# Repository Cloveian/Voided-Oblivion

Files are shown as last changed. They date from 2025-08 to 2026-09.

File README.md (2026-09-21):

# Voided Oblivion

**An infinitely\* tileable analog hall-effect keyboard.** 5×6 ortholinear tiles that snap together edge to edge in any\*\* arrangement, two tiles for a 60%, three for an 80%, four for
full size. Each tile is a complete unit with its own RP2350B, dual USB-C PD ports, and power
system.

Designed by **Clover**

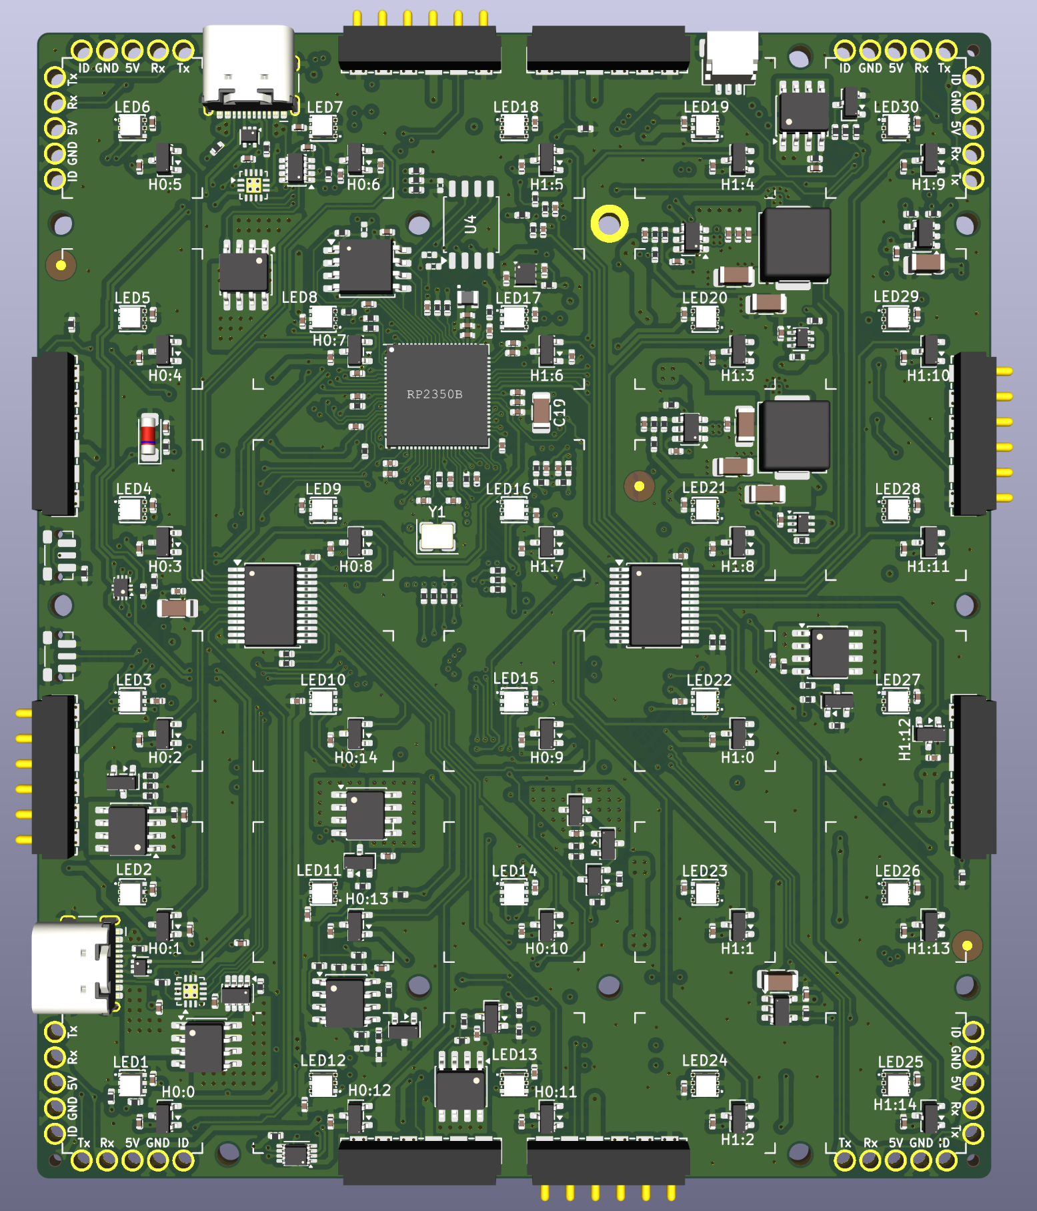
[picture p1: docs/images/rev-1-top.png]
Voided Oblivion, top

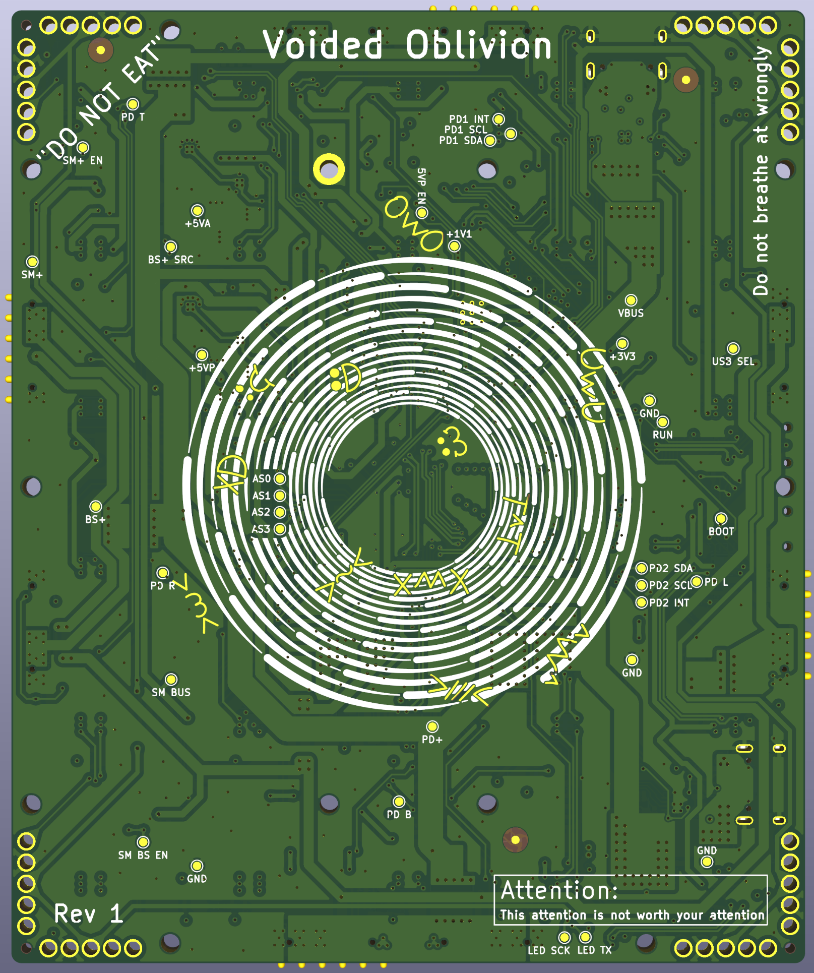
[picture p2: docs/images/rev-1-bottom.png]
Voided Oblivion, bottom


**Status: design complete, ordering boards.**

<sub>* not actually infinite but like way more than reasonable.</sub>
<sub>** in a grid, and not 6x5 to 5x6, individual tiles need to be the same orientation (portrait or landscape; they can be rotated 180° tho)</sub>

---

## At a glance

| | |
| --- | --- |
| **Board** | 4-layer, ~425 components, 242 nets |
| **MCU** | **RP2350** (used like 44/48 GPIO, i dont think i used enough 𐔌˙.) |
| **Dual USB** | 2 USB-C ports for ease of use when rotating the module(s) 90° |
| **Power** | FUSB302 PD port(s), TPS54302 bucks, comparator-based VBUS→PD/BS handoff |
| **Sensing** | Analog hall effect, 74HC4067 muxes into the ADC, 30 keys/tile |
| **Performance** | 1000 Hz polling, sub-1 ms latency, rapid trigger (in theory, if firmware is good at firmware-ing) |
| **Time** | ~100 hours spent on this project |

---

## The parts i find most interesting/difficult

**Stupid people ~~proofing~~ resistant-ing.** *so* many things would have been so much easier if i were just designing this for myself, but i'm not. i had to think of random scenarios like *'what if someone plugs both USBs in at the same time?'*, i had to add protection circuits for that. 'what if someone wanted to put 64 of them together?' (ok that one i would do if i had that many >w<) and minimizing the damage that a short between the outer pogo pins can do, and several other random things that i would just think 'i wont do that'

**Power system.** this project uses USB power delivery for 2 main reasons. non PD is not enough power for more than like 1 tile (with rgb) and with PD i can run a higher voltage across the whole network without worrying about voltage drop. But PD comes with its problems, the switch from 5v to higher voltages, i designed a comparator based system so all the power routing would happen with hardware so a firmware mistake ~~wouldn't~~ couldn't fry anything.
→ [power](docs/schematic-design/power.md)

**Everything budgeted onto one MCU.** 44 of 48 GPIO, 6 of 8 ADC channels, 12 of 12 PIO state machines. The interesting thing is that PIO uart is faster than hardware uart.
→ [pin budget](docs/design-choices/pin-budget.md)

---

## What's in here

| | |
| --- | --- |
| [`Voided-Oblivion/`](Voided-Oblivion/) | KiCad files |
| [`docs/`](docs/) | the design documentation |
| [`layouts/`](layouts/) | (proposed) keymaps made with [keyboard-layout-editor](http://www.keyboard-layout-editor.com/) |
| [`graphics/`](graphics/) | silkscreen art |

I removed the Datasheets from repo cuz they're manufacturer IP, and i would like to not make any enemies
[`docs/datasheets.md`](docs/datasheets.md) indexes every part and where to get its datasheet.
`old/` (the first attempt) is out of the working tree but still in git history.

## Reading the docs

These are working engineering documents, they were written during the design process (how it should be), and i keep incorrect reasoning/assumptions to remember *why* something changed

- **design**
	- [chip list](docs/chips.md)
	- [schematic ~~meth~~ math](docs/schematic-design/index.md)
- **features n' stuff**
	- [design decisions](docs/design-choices/index.md)
	- [goals and constraints](docs/goals.md)
- **sanity check(s)** (check if my sanity was still intack after reading so much (not quite) 'ai slop' ꩜ ᨓ𖦹)
	- [design reviews](docs/schematic-review-2026-08-08.md)
	- [datasheet research](docs/research/README.md)

## Licence

[CC BY-NC-SA 4.0](LICENSE.md), with a relaxed NonCommercial term so it only catches people actually making money. Mostly just do whatever, i would like some credit tho (,,¬﹏¬,,)

The carve-outs (full stuff in [LICENSE.md](LICENSE.md)):

- **Under US$1,000/year in revenue, sell freely.** No permission needed, nothing owed. The NonCommercial term is just to stop some small-medium sized company profiting off *my* work. I support the community and don't want to stop group buys or making a few for a friend or something like that.
- **If you do want to sell** (more than $1000) just talk to me (issue probably works) we can work out some sort of compensation. I probably won't say no.
- **The connector interface(s) are public domain** anyone can make/design their own submodule or even own tile if they want, it's encouraged ദ്ദി ˉ͈̀꒳ˉ͈́ )✧ 

## On LLM use

i used LLMs while working on this, ima just say how they were used.

**what they did:** the [datasheet research pages](docs/research/README.md) were written by agents that were given a datasheet and what the chip was supposed to do, and *not* shown my schematic so their conclusions could be diffed against what i'd actually designed. same shape for the [review passes](docs/electrical-review-2026-08-20.md), caught errors i made by looking at things too close. they also helped with editing the docs some, and wrote some of the tooling in `scripts/`.

**what they didn't:** ideas, design decisions, the modular architecture, the schematic, and the layout are mine. all the ideas in [schematic-design](docs/schematic-design/index.md) are mine. for example, some of the LLM research was different than what i had designed in the schematic, it exposed some mistakes i had made, and sometimes the research was backwards and would have me make a switch that couldn't turn on. the actual choices genuinely couldn't be made by a llm and this still be a good project

also a lot of the reviews were mostly useless/irrelevant 'fluff' (immediately dismissable with 0.8ms of thought with context (￢ \_￢ ) ) but did actually catch real stuff that needed fixing

also, and i say this as someone who has spent over 100 hours on this project: LLMs could *not*
have done this. they really, really suck at it. trust me, i would know.

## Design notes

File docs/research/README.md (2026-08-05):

# Datasheet research (auto-generated)

These pages are **not written in my voice** and are **not design decisions**. Each one was produced by an agent that was given:

- the project's power architecture and constraints,
- the role a given chip has to play,
- the datasheet,

and *deliberately not shown the current schematic*. So each is an independent "here's what the datasheet says the right way to do this is," written without knowing what I actually drew.

The point is to **diff them against the as-built design** and see where they disagree. Where they agree, that's a cross-check. Where they disagree, that's either a bug in my schematic or a thing the agent missed - and either way it's worth a look before fab.

Values here are *proposals*, not decisions. Anything I adopt gets written up properly in [schematic-design](../schematic-design/index.md) with my own reasoning, and the part lands in [chips](../chips.md).

**Caveat added after these were written:** the agents were briefed that i was hand-assembling on a hotplate with low-temp bismuth paste. **that's no longer true - this is going to JLC assembled.** so anywhere one of these pages rejects a package or a part on *solderability* grounds, that reasoning is void (the sourcing, cost and PCB-design-rule arguments still stand). The affected calls are the MAX40203 WLP package in [ldo-and-ideal-diode](ldo-and-ideal-diode.md) and the reflow-profile discussion in [sk9822-and-level-shifter](sk9822-and-level-shifter.md). Background in the [hall-effect re-revisit](../design-choices/hall-effect-sensors.md#re-revisit-im-not-assembling-this-myself-anymore).

**There is deliberately no RP2350B page here.** That one's the centrepiece of the whole design and the reasoning *is* the project, so i'm doing it myself rather than reading someone else's summary of it. Its working goes in [mcu](../schematic-design/mcu.md) like everything else i actually decide.

---
Back to [main index](../index.md)

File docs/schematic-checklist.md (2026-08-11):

# Single-Tile Schematic Checklist

Everything that has to land in the KiCad schematic for **one tile**. Pulled from [chips](chips.md), [pin-budget](design-choices/pin-budget.md), [power](design-choices/power.md), [comms](design-choices/comms.md), [hall-effect-sensors](design-choices/hall-effect-sensors.md), and [module-connectors](design-choices/module-connectors.md). One tile does everything - no second MCU - so this is the whole board.

Pin numbers are the **starting assignment** from [pin-budget](design-choices/pin-budget.md#a-starting-assignment) (KiCad gets final say when routing). Budget targets: **44/48 GPIO, 6/8 ADC, 12/12 PIO SMs.**

---

## 1. MCU + boot

- [ ] **RP2350B** (QFN-80), 1×
- [ ] Decoupling: 100nF per power pin + bulk caps per datasheet
- [ ] Crystal (12MHz) + load caps, or confirm using internal - Void needs accurate USB so **crystal**
- [ ] USB DP/DM to the USB mux (see §6), with 27Ω series + ESD if not handled by mux
- [ ] BOOTSEL button (or test pad) for UF2 flashing
- [ ] RUN/reset button or pad
- [ ] SWD header (SWCLK/SWDIO/GND/3V3) - do **not** skip, you'll want it
- [ ] **W25Q128JVS** 16MB QSPI flash on the QMI bus (steno dict)
  - [ ] Resolve first: boot flash only, or this as a 2nd chip on **CS1n (GPIO19)**? Checklist assumes 2nd chip (37/48). If boot-only, drop GPIO19 → 36/48.
- [ ] FIDO2 = TrustZone, internal, **no external secure element to wire**

## 2. Power - rails & regulators

See [power](design-choices/power.md) for the full flow. Three rails: **HV** (per-side switched), **bootstrap 5V** (always-on, shared), **clean 3.3V** (LDO). GND common everywhere.

- [x] **FUSB302BMPX** USB-PD PHY - I²C0 **SDA GPIO20 / SCL GPIO21**, **INT GPIO15**, CC1/CC2 from the active port (via CC mux, §6)
- [x] **TPS54302** ×2 (same part, 2 BOM instances):
  - [x] **Clean buck** (HV→5V, always-on) - input must work from ~5.5V (pre-PD) through 20V; feeds the LDO + OR's onto bootstrap
  - [x] **Big buck** (HV→5V, gated) - enable on **GPIO14**; feeds RGB + submodules
  - [x] Each: inductor, input/output caps, feedback divider for 5V per datasheet
- [x] **XC6220B331MR** 3.3V LDO off clean 5V - feeds MCU + hall sensors + mux (low-noise, this is the analog rail). **5-pin SOT-25 with a CE pin - tie CE to VIN** (always-on clean rail, must never gate off)
- [x] ~~**MAX40203**~~ → **LM66100DCKT** (C2832141) ideal diode - clean buck 5V → shared **bootstrap** net
  - [ ] **CE (3) → VOUT/BS+ via R15 0Ω** — always-on RCB. CE to GND silently disables reverse blocking
  - [ ] **C114 100nF → 1µF** on VIN, local to the part
  - [ ] **R83 100k: ST (5) → +3V3** (*not* VOUT — 5V would exceed RP2350's 3.6V pin max), ST → `BS+ SRC` GPIO
  - [ ] Pin 4 (N/C) → GND or no-connect flag
  - [ ] Symbol + footprint (SC-70-6) + Value + **LCSC** all move together — the BOM pulls Value

## 3. Power - VBUS handoff & HV switching (hardware, no firmware)

- [ ] **TLV1805** comparator watching VBUS vs ~6V resistor divider, drives two things at once:
  - [ ] **AO3415** P-FET: VBUS→bootstrap path, normally on, comparator turns OFF above ~6V
  - [ ] N-FET/switch: VBUS→local HV rail, normally off, comparator turns ON above ~6V
- [ ] **AO4407A** ×4 (Q4–Q7) - HV per-side switches (one per edge), SOP-8 P-FET, 30V/9.5mΩ, **≥2A continuous** design target against the connector's 4A ceiling. RC soft-start on gate (values below). ~~AO3401A ×4~~ - SOT-23 couldn't survive the connector's full current, [working](schematic-design/power.md#hv-per-side-switches---picking-the-fet)
  - [ ] **BC847B** (C20069135) ×4 - NPN level-shift, **Basic**. MCU GPIO0–3 → base → pulls the gate toward GND through R_soft
  - [x] ~~**BZX84C10** ×4 gate clamps~~ - **cut.** AO4407A is ±25V, and at the 9V default Vgs is only −8.6V (35% of rating). They'd protect the flagged 20V mode only, for ~32mm² of scarce board
  - [ ] Gate network per switch, [corrected values](schematic-design/power.md#gate-drive---the-researchs-values-are-backwards) - **the research's 39k/470k is backwards and won't turn on at 9V**:
    - [ ] **R_pu 100kΩ** gate→source · **R_soft 4.7kΩ** NPN collector→gate · **C_soft 100nF** gate→source
    - [ ] **Rb 10kΩ** GPIO→base · **Rbe 100kΩ** base→GND
    - [ ] → Vgs = −0.955 × PD+ (−8.6V @ 9V, −19.1V @ 20V), t_ramp ≈ 1ms, ~0.5A inrush
  - [ ] HV enable GPIO: **GPIO0–3** (one per side)
  - [x] ~~HV per-side current sense → ADC GPIO42–45~~ - **cut entirely, not even DNP footprints.** A DNP pad costs the same board area as a populated one, and area is the binding constraint. Re-decision + weighted table in [design-choices/power](design-choices/power.md#re-decision-does-this-need-per-edge-ocp-at-all)
    - **ADC budget drops 6/8 → 2/8. GPIO42–45 are free.**
    - **!firmware-note!** **FIRMWARE now owns overcurrent** - limit topology *before* enabling a path, using the tile map it already builds. Prevention, not tripping
- [ ] **Wire the switch source to PD+ and the drain to the connector**, not the reverse - that orientation points every tile's body diode inward, so two neighbours with both switches open sit diode-to-diode and the edge net floats. Flipped, every tile permanently powers its neighbours. [why](schematic-design/power.md#the-body-diode---an-open-switch-only-blocks-outbound)
- [ ] **!firmware-note!** **FIRMWARE: turn an edge switch OFF on neighbour loss.** An edge left enabled after a tile is yanked makes the next hotplug a hard hot-insert - the new tile's bulk charges through its own body diode with no soft-start in the path. This is what makes the Rx pull-down detection in §7 load-bearing
- [ ] **SS54** Schottky ×(per VBUS→HV path) - backfeed protection (40V/5A)
- [ ] Hold-up caps on bootstrap to cover the µs comparator→buck handoff

## 4. Key sensing

- [ ] **GH39F** hall sensor ×30 (5×6) - generic 3-pin SOT-23 footprint (Vcc/OUT/GND) so any analog hall drops in
- [ ] **74HC4067** 16:1 analog mux ×2
  - [ ] Mux outputs → ADC **GPIO40, 41**
  - [ ] Shared 4 select lines → **GPIO8–11**
  - [ ] 30 keys into 32 channels = 2 spare channels (leave unconnected/test pads)
- [x] ~~Consider sensor **bank-power gating**~~ - **decided against** ([working](schematic-design/keys.md#sensor-bank-power-gating)). Fixed the LDO instead. Do route sensor VDD as its own net with a 0Ω link to +3V3 so it can be retrofitted.
- [ ] Tie the 2 spare mux channels (AM0:15, AM1:15) to GND - currently floating
- [ ] Sensors on the **clean 3.3V** rail, kept off the noisy buck

## 5. RGB

- [ ] **SK9822-EC20** ×30 - daisy-chained
- [ ] Hardware **SPI0**: SCK **GPIO34**, TX(MOSI) **GPIO35**
- [ ] Powered from the **big (gated) buck** 5V, NOT the clean rail
- [ ] **SN74LVC2T45** level shifter 3.3V→5V on SCK/data - **required**, not conditional (SK9822-EC20 VIH min 3.4V > the 3.366V the 3V3 rail can manage). VCCA→3V3, VCCB→gated-5V, DIR high. 22–33Ω series on the 5V side. See [rgb calcs](schematic-design/rgb.md#picking-the-level-shifter)
- [ ] Bulk cap near the LED chain; per-LED decoupling per density

## 6. USB-C (dual port + mux)

- [ ] 2× USB-C receptacles (one horizontal edge, one vertical edge - for 90° reach)
- [ ] **TMUX1574PWR** - muxes CC1/CC2/DP/DM between both ports, single SEL driven by VBUS-A detect
  - [ ] 100Ω series on CC lines (ESD)
  - [ ] Rd pull-downs on the RP2350B side
  - [ ] VBUS-A → SEL detect circuit (resistor/transistor)
- [ ] Selected port's CC → single FUSB302 (§2); non-selected port can't negotiate (stays 5V)
- [ ] VBUS from both ports → backfeed protection (§3)

## 7. Inter-tile edge connectors (×4 sides)

Per side carries: **HV, Bootstrap, GND, Tx, Rx**. **Part picked: PG-6P-2.5-5.5H-SM-RA** (Shenzhen Yiwei), **2 per side** - one 6P male + one 6P female. Pinout is the palindrome with power ×4, gender split falling out of the two bodies - see [module-connectors](design-choices/module-connectors.md#revisit-i-picked-a-real-connector-and-it-killed-the-custom-cutout-idea):

```
GND  GND  HV   HV   BS   Tx   |   Rx   BS   HV   HV   GND  GND
<--------- 6P male --------->  |  <-------- 6P female ------->
pin:  1    2    3    4   5   6 |   1    2    3    4    5    6
```

**GND outboard** (deliberate - the most exposed contacts should be ground, not the 20V rail). Per body: male = `GND GND HV HV BS Tx`, female = `Rx BS HV HV GND GND`.

- [ ] Two footprints: **short (5un edge)** and **long (6un edge)** - like only mates like
- [x] **Gender rule: clockwise around the perimeter, every edge is male-then-female.** Top L→R, Right T→B, Bottom R→L, Left B→T. Two neighbouring tiles traverse the shared edge in *opposite* rotational senses, so male always lands on female. Drawn as J1/J3/J7/J5 male, J2/J4/J8/J6 female
- [ ] **Both bodies symmetric about the edge midline** - this is the one that silently maps HV onto Tx if you get it wrong
- [ ] HV/GND get **4 contacts each** (1A per contact → **4A per-side ceiling**, which is what sizes Q4–Q7 in §3)
- [ ] Rx line **pulldown, 4.7kΩ** per side to GND - **required by RP2350-E9**, which sources ~120µA and parks a floating input at 2.2V (phantom neighbour). 8.2k is the datasheet's boundary with only 171mV to VIL; 10k **fails**. [working](schematic-design/mcu.md#rp2350-e9-and-the-neighbour-detect-pull-downs)
- [ ] Tx series-termination footprint per side, **populate 0Ω** (pads for 22–33Ω if it rings at 4 Mbaud)
- [ ] **Inter-tile UART pins - all four sides on PIO** ([why](design-choices/comms.md#revisit-the-piosm-allocation-was-built-on-a-wrong-assumption)): the hardware UARTs moved to submodule corners, because the PL011 caps at **7.8 Mbaud** while a PIO UART does ~18.75 - the slow path was on the high-traffic links
  - [ ] **Top** GPIO12/13 · **Left** GPIO16/17 · **Bottom** GPIO4/5 · **Right** GPIO6/7 — all PIO (F6/F7/F8), uniform, **no F11 anywhere**
  - [ ] Pins no longer need to be UART-capable; left as-is to avoid churn
- [ ] ~~Footprint placeholder pending pogo-vs-spring-finger prototype~~ - **resolved**, it's an off-the-shelf pogo pair. Footprint still needs drawing from the part drawing
- [ ] **No inset sequencing is possible** with molded bodies - all 12 contacts break together, so hot-unplug safety rests on PD voltage. Default **9V** - unconditionally under gold's ~15V minimum arcing voltage. (**not 12V** - 12V isn't a required PD step, the Power Rules give 9/15/20. 15V is only arc-safe breaking ≤1 tile, since an arc needs 15V **and** 0.4A.) 20V behind an explicit firmware flag + warning

## 8. Submodule corner connectors (×4 corners)

**5-pin** (revised from 4 — [working](design-choices/submodules.md#revision-5-pins-not-4---adding-a-senseid-line)), clockwise-consistent at every corner:

```
ID   GND  5V   Rx   Tx
 1    2    3    4    5
```

- [ ] **`ID GND 5V Rx Tx`** — prepend ID, don't append. 5V must stay **interior** (a misaligned module can't land it on a signal pin); ID sits at an end next to GND, the quietest pin
- [ ] 5V from the **submodule group switch** (below); independent UART per corner, not muxed
- [ ] Corner Tx/Rx → **GPIO22–29** — **2 corners on hardware UART, 2 on PIO**:
  - [ ] **GPIO24/25 = UART1 TX/RX (F2)** and **GPIO28/29 = UART0 TX/RX (F2)** — the only two pairs in that range that are TX/RX at F2, and conveniently on *different* UARTs
  - [ ] **GPIO22/23 and GPIO26/27 on PIO** — both are UART1 CTS/RTS at F2, so they could never have paired with each other anyway
- [ ] **ID → 4× ADC-capable GPIO** (from GPIO42–47), **pull-up to +3V3** (not 5V), **series ~10kΩ** to the pin — the module is an untrusted 5V load
- [ ] **Corner power is dual-sourced** so submodules work on a 5V-only (non-PD) source - [working](design-choices/submodules.md#corner-power-dual-sourced-so-submodules-work-without-pd)
  - [ ] **U15 LM66100DCKT**: +5VP → SM_BUS, **CE→VOUT via 0Ω** (always-on reverse blocking). No GPIO — +5VP is genuinely 0V pre-PD, so there's nothing to arbitrate
  - [ ] **U12 AP2171WG-7**: BS+ → SM_BUS, EN = `SM BS EN`. **!firmware-note! Firmware rule: enable only while `BS+ SRC` reads low** (clean buck not feeding BS+)
  - [ ] **U16 AP2171WG-7**: SM_BUS → SM+, EN = `SM EN`. This is the independent gate — U15 has no enable, so without it the only post-PD off-switch is the big buck, which kills RGB too
  - [ ] **Both AP2171W enables: 4.7kΩ pull-down to GND** — *not* 100k, *not* 0Ω. RP2350-E9 parks a floating pad at 2.2V, above the EN threshold, so a mis-configured pin can turn the rail **on**
  - [ ] **U16 /FLG → `SM FLT` GPIO** with 100k pull-up to +3V3. **U12 /FLG and U15 ST: no-connect flags, no pull-ups** — U12 is in series with U16 at the same 1A so it reports the identical fault, and U15's ST duplicates `BS+ SRC`
  - [ ] Caps: 1µF at each IN, 10µF on SM_BUS and SM+
  - [ ] **CHECK BEFORE FAB: does AP2171W's OCP latch or auto-retry?** If it latches, U16's EN is the only fault reset
- [ ] Mechanical keying (shrouded header / asymmetric mount) — pin order limits misinsertion damage, it doesn't prevent it
- [ ] **4-pin machined (Swiss) socket → now 5-pin**, socket on the tile

**Notes:** the ID divider runs off +3V3, so presence and identity work **with the corner rail switched off** — firmware can read what's plugged in before deciding to power it. A module needs **no MCU**: firmware just doesn't configure UART on Tx/Rx and uses them as GPIO.

**Not provided:** 5V-only (non-PD) operation, and submodules-alive-with-RGB-off. The switch is downstream of +5VP so it can only remove power. RGB dimming is the SK9822 global-brightness lever, not a rail gate.

## 9. Pin assignment cross-check (paste into schematic notes)

| Pins | Use |
| --- | --- |
| GPIO0–3 | HV per-side enable |
| GPIO4/5 + 6/7 | Inter-tile Bottom + Right (UART1) |
| GPIO8–11 | Key mux select lines |
| GPIO12/13 + 16/17 | Inter-tile Top + Left (UART0) |
| GPIO14 | Big buck enable |
| GPIO15 | FUSB302 INT |
| GPIO19 | Steno flash CS1n (if 2nd chip) |
| GPIO20/21 | FUSB302 I²C0 SDA/SCL |
| GPIO22–29 | Submodule corners (4× Tx/Rx) |
| GPIO34/35 | RGB SPI0 SCK/TX |
| GPIO40, 41 | Key mux A/B ADC outputs |
| GPIO42–45 | **Submodule corner ID / analog** (4× ADC) |
| **Spare** | GPIO18, 30–33, 36–39, 46, 47 (11 free) |

**ADC:** 6/8 used · **GPIO:** 44/48 used · **PIO SMs:** 12/12 (RGB on HW SPI; **4 inter-tile sides on PIO = 8**; 2 submodule corners on HW UART, 2 on PIO = 4)

## 10. Before first PCB / sanity

- [ ] ERC clean
- [ ] Confirm every ADC-needed net actually lands on GPIO40–47 (hard constraint)
- [ ] Confirm both RGB SPI nets are the **same** SPI instance
- [ ] Test points: 3V3, 5V bootstrap, HV, GND, key-mux out, a couple UART lines
- [ ] Decoupling sweep - every IC has its caps
- [ ] **Blocked-on-hardware** (don't gate the schematic, just remember): case-magnet field vs hall saturation, pogo vs spring-finger, XC6206/MAX40203 downgrade triggers

---

Back to [index](index.md).

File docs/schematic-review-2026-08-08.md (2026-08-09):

# Voided Oblivion — Schematic Design Review

**Date:** 2026-08-08 · **Scope:** `Voided-Oblivion/Voided-Oblivion.kicad_sch` (+ `keys.kicad_sch`, `power.kicad_sch`), KiCad 10 · **Analysis run:** `analysis/2026-08-08_2107/`

## Verdict

**The schematic is in very good shape.** No board-killing electrical error was found. Every IC subsystem was traced pin-by-pin and, where datasheets exist, verified against the manufacturer PDF. The design closely follows the RP2350 hardware design guide where it applies, and the project's own docs (`docs/schematic-design/*`) already contain unusually rigorous derivations that the schematic matches. What remains before fab: **the sourcing gap (1% MPN coverage), a PCB that is one design generation behind the schematic, and a short list of latent/provision bugs and cheap-insurance items below.**

## Analyses run

| Analysis | Status | Result |
|---|---|---|
| `analyze_schematic.py` | ✅ | 374 components, 280 nets, 120 findings (4 error, 17 warning — triaged below) |
| `analyze_pcb.py --full` | ✅ | Used for sync check only — layout is mid-progress |
| `cross_analysis.py` | ✅ | 10 findings (all schematic↔PCB sync) |
| EMC (`analyze_emc.py`) | ✅ | 35.5/100 — **provisional**: findings are dominated by the unfinished layout (no ground zones/fills yet). Re-run after layout. |
| SPICE (ngspice) | ✅ | **35/36 subcircuits pass**, 1 warn (C37 — deliberately DNP, see below) |
| Thermal | ✅ | 0 findings (limited value until PCB is current) |
| KiCad ERC (`kicad-cli sch erc`) | ✅ | **1 error** — the intentional SM+ power-OR node (see F3) |
| Deep review + gate | ✅ | 14 findings verified, 0 quarantined (`analysis/deep_review.json`) |
| Gerber analysis | — | Not applicable — no fabrication outputs exist yet |
| Lifecycle audit | — | Not run — MPN coverage is 1%, nothing to query. Re-run after BOM backfill. |
| Prior review delta | — | First review; no prior review file found |

**Verification basis:** Datasheets in `Refrences/datasheets/` were used as ground truth (RP2350 datasheet + hardware design guide, TPS54302, LM66100, TLV431, LM2903, AO3401A, AO4407A, FUSB302, ABM8-272, W25Q128JV, 74HC4067, GH39F/SS49E, SK9822, SN74LVC2T45, TPD2E2U06, SS54, BZX84, BZV55, APH0630). The **TLV767 datasheet was missing and was fetched during this review** (TI SLVSE84D — recommend saving it to `Refrences/datasheets/`). The **AP2171W datasheet is missing** — U12/U16 are verified only against the KiCad library symbol and convention (see F3).

---

## Findings

### Warnings (fix or decide before layout freeze)

**F1 — CC1/CC2 are crossed on both USB-C ports.**
`USB1.A5 (CC1) → R49 → PD1.CC2` and `USB1.B5 (CC2) → R48 → PD1.CC1`; USB2/PD2 are crossed identically via R50/R51. For a UFP sink using only USB 2.0 data this survives — the FUSB302 measures both CC pins and just reports mirrored cable orientation — but anything orientation-dependent (VCONN targeting, future SS mux control) acts on the wrong pin. Either straighten it or add a schematic note making the cross deliberate so firmware knows to flip orientation.

**F2 — The second-flash CS provision can never work as drawn.**
The provision net named `GPIO0` contains only R9.1 and R11.1 — it is an island, not connected to U1 pin 77 (whose net is `PD EN TOP`). Populating U4/R11/R13 would leave U4's CS undriven (R13's pull-up would at least hold it deselected). Deeper problem: XIP_SS_N_1 exists **only on GPIO0, GPIO8, GPIO19, GPIO47** (verified in the RP2350 datasheet GPIO CTRL register map), and GPIO0/GPIO8 are spent (PD EN TOP, AS0). **Fix:** move the provision wire to GPIO19 or GPIO47 — both are currently unused stubs. Latent (everything involved is DNP), but it silently defeats the documented second-flash option.

**F3 — SM+ power-OR node: intentional, but carries the review's one ERC error and one unverified part.**
ERC flags `U12.OUT ∥ U15.VOUT` (power-output × power-output). The topology is right: U15 (LM66100, CE→VOUT via R16 = always-on reverse-blocking mode, same strap as U9/R15 and correct per LM66100 §8.3.2) ORs +5VP onto the node; U12 (AP2171W) switches BS+ onto it pre-PD; U16 gates the result to SM+. Two follow-ups: (a) add an ERC exclusion with a comment; (b) **the AP2171W datasheet isn't in the project** — confirm active-high EN, off-state reverse blocking, and current limit vs. SM+ worst-case load. Note that while U12 is enabled it conducts both directions, so if +5VP comes up with U12 still on, +5VP back-feeds BS+ — probably harmless at ~5V, but it's a firmware sequencing rule worth writing down.

**F4 — PCB is one generation behind the schematic.**
66 schematic components missing from the board; stale parts on it: U9 still MAX40203 (now LM66100), D3 still BZV55B**5V1** (now B**3V3**), C41 still 100µF on BS+ (now 1µF on +5VA), R48/R50 0Ω (now 100Ω), C76/C77/C114/R23 values stale. All match documented re-selects, confirming the schematic is truth. Run **Update PCB from Schematic** before any further layout; treat current EMC/PCB analyzer output as provisional.

**F5 — Sourcing blocker stands (SS-001).**
MPN fields readable by tooling: 1/77 unique parts (1.3%). The docs contain many settled picks (APH0630T100M C5349698, LM66100 C2832141, …) that aren't in symbol fields. Backfill LCSC/MPN/Manufacturer fields (the `bom` workflow can drive this) — it's the one thing that hard-blocks a JLC order.

### Recommendations (cheap insurance / open items from your own docs)

**F6 — ADC_AVDD is tied straight to +3V3.** The reference design does this too, but this board's entire key mechanism is 12-bit sampling of 30 hall sensors, and your docs call the supply chain feeding it "not characterised end-to-end" and "the first suspect." VREG_AVDD got an RC filter (R3 33Ω + C9 4.7µF); ADC_AVDD got nothing. Add a DNP-able filter provision (0Ω default, ferrite/33Ω + 1–4.7µF option) between +3V3 and pin 59. Costs nothing now, impossible after layout.

**F7 — Sensor-VDD split (keys.md's own to-do) is not implemented.** All 30 GH39F VDD pins tie directly to +3V3; the "0Ω link on its own net" that keeps the bank-gating retrofit possible does not exist yet.

**F8 — R30/R31 tolerance not encoded.** power.md's margin analysis wants 0.5% here (worst-case LTP 5.52V RSS vs the 5.5V vSafe5V ceiling — the thinnest margin on the board). U10 is already TLV431B (±0.5%) ✅; put the 0.5% tolerance in the R30/R31 fields so the BOM actually orders it.

**F9 — No ESD protection on submodule/inter-tile UART lines.** TPD2E2U06 covers both USB data pairs ✅. The 8 corner submodule UART lines (user-facing, hot-plug by design) and 8 tile-edge UARTs have none. Consider a 4-channel TVS per corner, or at least series resistors for hot-plug.

**F10 — No connector-side VBUS capacitance.** Connector VBUS nets carry only the FUSB302 sense pin and SS54 anodes; the only cap is C38 100nF behind the diodes. The deliberate 10µF-attach-limit strategy is sound, but ~1µF per port before D1/D2 would still be inside the limit and gives FUSB302 a cleaner measurement node.

**F11 — 100Ω CC series resistors (R48–R51).** Rd seen by the source becomes 5.2k (+2%, inside the 4.59–6.12k window) and BMC is unaffected — fine for a sink. VCONN *sourcing* through 100Ω is impossible, but a sink doesn't need it. Keep if intended as hot-plug/ESD damping; document why, since the PCB still has 0Ω.

**F12 — Five spare GPIOs (19, 38, 39, 46, 47) end in bare wire stubs.** Harmless, but label them or add test points; reserve GPIO19 or GPIO47 for F2.

**F13 — 22µF output caps (C28/C29/C34/C35) have no footprint/MPN yet.** When assigning, they must be ≥0805-class 6.3V+ X5R/X7R — a 0402 22µF loses ~half its capacitance at 5V bias, and the 44µF total is what the TI Table 7-2 stability design assumes.

**F14 — Doc drift:** power.md's LDO section still documents XC6220B331MR; as-built U7 is TLV76733. The swap is *good* (see below) — update the doc, and save the TLV767 PDF into `Refrences/datasheets/`.

### Analyzer false positives (triaged, no action)

- **PP-001 "U16.5 IN has no DC path to a power rail"** — the pin is fed by U15/U12 switch outputs on the OR node. Powered; false positive.
- **RS-001 "+5VA EN / +5VP EN have no declared source"** — they're enable nets that merely *look* like rails to the parser (`+5…` prefix). +5VA EN is U11B open-collector + R34 100k→3V3; +5VP EN is GPIO14 + R38 100k pull-down. Both correct. (Renaming, e.g. `5VA_EN`, would silence tooling.)
- **VM-001 "BS+ SRC 5V/3.3V domain crossing"** — BS+ SRC is the LM66100 open-drain status pin pulled to +3V3 by R83, exactly as your docs specify ("don't copy TI's pull-up rail"). Correct.
- **UC-003 "CC missing 5.1k pull-downs"** — Rd is integrated in the FUSB302. Correct as drawn.
- **UC-002 "no ESD on VBUS"** — partially true (see F10), but the D+/D- pairs *are* protected (U13/U14), and VBUS goes through Schottky ORing + soft-started FETs, not directly to loads.
- **SPICE warn on C37** — the TLV431 cathode cap the docs already recommend keeping DNP (unstable 6nF–400nF band). It *is* DNP. Consistent.
- **EMC errors (no ground plane, decoupling distance, IO filtering)** — artifacts of the half-built layout; re-run after F4.

---

## What was verified correct (the positive findings)

**RP2350B core (U1)** — all against the datasheet + hardware design guide:
- All 8 IOVDD pins → +3V3; 3× DVDD → +1V1; VREG loop verified: VREG_VIN=3V3, LX→L1 3.3µH→+1V1, FB sensed at +1V1, VREG_AVDD through R3 33Ω + C9 4.7µF (guide values), VREG_PGND→GND. USB_OTP_VDD→3V3 ✅
- Crystal: ABM8-272-T3 (the Pico 2 part, CL=10pF) + 15pF/15pF (CL_eff ≈ 10.5pF) + 1kΩ XOUT series — the guide's exact circuit ✅
- USB: DP/DM through 27Ω series (R7/R8) to the TS3USB30E mux ✅
- Flash: W25Q128JVS (the guide's own chip) on QSPI, CS strap network exactly per guide (R10 0Ω link, R1 DNF pull-up, R6 1k + BOOTSEL to GND); second-flash provision DNP (but see F2) ✅
- RUN: button-only, matching the Minimal/Pico 2 practice; SWD on dedicated J9 header ✅
- Pin budget matches `pin-budget.md`: 4 side UARTs, 4 corner submodule UARTs + 4 ADC ID lines, 4 PD-EN, I2C ×2 + INT ×2 for the PD PHYs, AS0–3 mux address, 2 ADC mux returns, LED SCK/TX, 5 power-control GPIOs, 5 spare ✅

**Power (all SPICE-checked, values match `power.md` derivations):**
- U5/U6 TPS54302: FB 100k/13.3k → 5.08V (Vref 0.596V per SLVSDG6C), 10µH APH0630T100M (Isat 4.57A vs 2.47A peak), 2×22µF out, bootstrap caps, feedforward 75pF ✅
- U7 TLV76733: **pinout verified against TI SLVSE84D Table 5-1** (OUT/SNS/GND/EN/GND/IN — the symbol is right), SNS→OUT, EN→IN via R12 0Ω (explicitly sanctioned; internal pull-up), CIN 1µF / COUT 4.7µF meet the 1µF minima — this answers power.md's open "is 1µF in OK" question with a datasheet **yes**. The WSON-6 pad also dissolves the XC6220 thermal ceiling that made bank gating load-bearing (≈+41°C at 400mA vs +113°C) ✅
- U9/U15 LM66100: CE→VOUT reverse-current-blocking strap on **both** (R15/R16) — the exact trap power.md warns about, avoided twice; ST pulled to +3V3 not VOUT ✅
- U10 TLV431**B** + R21 20k bias (188µA ≥ 2.35× IK(min)); R27 0Ω REF strap; C37 DNP per doc recommendation ✅
- U11 LM2903: VCC=VBUS (can't eat its own tail), A-side hysteresis on the reference node (R22/R46 → UTP 5.95V / LTP 5.68V), B-side clean 5.73V buck-enable — matches the doc's derivation; divider R30/R31 44.2k/12.2k confirmed ✅
- Q1 AO3401: off-divider R35 1M / R36 10k (Vgs −0.2V at 20V), **D5 gate zener present** — the single-fault clamp power.md recommended adding has been added ✅
- Q2/Q3/D4: gate network (R32/R29/R33/R47), D4 BZX84C10 clamp, C44 100nF Miller soft-start (~1–3ms PD+ ramp) ✅
- Per-side HV switches: 4× AO4407A (the doc's re-select away from SOT-23 thermal limits) + BC847 level shifters with 10k base/pull networks, drains to per-side PD nets on J1–J8 ✅
- SM+ chain: U12/U15/U16 with EN pull-downs (default off), FLG̅ pull-up 100k, BS+ SRC status to GPIO36 ✅

**USB/PD:** FUSB302 ×2 with VDD/VCONN on 3V3, I2C 4.7k pull-ups ×2 ports, INT pull-ups, VBUS sense direct to connector; TS3USB30E mux with OE̅ grounded, port-2-priority auto-select (USB2 VBUS → R37 10k → D3 3.3V clamp + C39 + R39 100k pull-down → S) — a clean hardware port arbiter; D1/D2 SS54 VBUS ORing ✅

**Keys & RGB:** 30× GH39F on +3V3 → AM0/AM1 (74HC4067, E̅ tied low via jumper, unused I15 grounded via R65/R66, 0Ω jumper convention on all select lines) → ADC0/ADC1; 30× SK9822 chain traced end-to-end (LED1→LED30, SDO/CKO chain intact, ends floating as expected), driven through SN74LVC2T45 (VCCA 3V3/VCCB +5VP, DIR strapped A→B, 33Ω series into the first LED; partial-power-down safe when +5VP is off) ✅

**ERC: 1 error total** (the intentional F3 node) — for a 374-component, 3-sheet hierarchical design that is remarkably clean.

## Review limits

- **AP2171W (U12/U16)** and **GH39FKSW** electrical limits verified only against library symbols/docs already in-repo; AP2171W PDF should be added (F3). GH39F's own PDF is present but thin (settling time unpublished — your keys.md already covers this).
- PCB, EMC, and thermal conclusions are deferred until the layout catches up with the schematic (F4).
- Lifecycle/pricing audit deferred until MPN backfill (F5).

*Full evidence-linked findings: `analysis/deep_review.json` (gate: 14 verified / 0 quarantined). Analyzer JSON: `analysis/2026-08-08_2107/`.*

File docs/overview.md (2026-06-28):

# Voided Oblivion

## What is this project?
This is a keyboard I have started, stopped, and restarted 3 times, but this time is different. This time I'ma actually write out my thoughts and design processes, so I can demonstrate my skills and abilities to future employers / college applications.
Also writing out my decisions will also make me more likely to not try and over achieve/cram as much stuff on this that can possibly fit.

The last 3 attempts didn't die because they didn't work, they stalled because i got too busy to finish, and by the time i came back i'd lost the thread and basically restarted, usually because i'd tunneled on a detail or wanted to cram in a new feature. So the real enemy here isn't technical, it's time. i'd get too busy, drop it, and by the time i came back i'd lost the thread. i've got the time this round, so writing everything down covers the rest: decisions stay made, and i can pick back up instead of starting over.

## What I'm working with
- Voron 2.4 (350mm$^{3}$) FDM printer
- Anycubic Photon mono x2 resin 3d printer
- Multiple soldering irons + hot air + 200mm$^{2}$ PCB reflow hotplate (SMD assembly)
- CNC that can in theory cut aluminum (never tested)
- Access to a very accurate laser powerful enough to cut aluminum

**Budget:** i'd like to stay around ~$250, but that's a guideline to keep me honest, not a hard limit.

## Background
This isn't my first keyboard. i've designed a Corne-shaped board in KiCad before, running a nice!nano v2 with Choc switches, per-key RGB, and resin-printed keycaps (back when i only had a worse-than-an-Ender-3 FDM printer and my resin one). So KiCad, per-key RGB, and printing my own caps are all known territory.

i'm also really good at 3D design in Fusion 360 (like, commission-level), and i daily-drive Arch.

---

The goals, constraints, and design decisions live in the [design doc](index.md).

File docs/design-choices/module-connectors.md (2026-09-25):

# Module Connectors

## Identify
I need to figure out the actual *physical* connector that mates one tile to its neighbor. the [pin-budget](pin-budget.md) and [comms](comms.md) pages decided what signals exist and which GPIO they live on, but nothing yet about the metal that bridges two tiles across an edge.

### what each edge connector has to carry
per side, between two neighboring tiles (from [power](power.md) + [comms](comms.md)):

| Net | what | rough current |
| --- | --- | --- |
| HV | negotiated PD rail, ~9–20V, per-side switched | up to ~4A (80% of 5A @ 20V) |
| Bootstrap | always-on shared 5V, boot + handshake | up to ~1.5A pre-PD |
| GND | common reference + return for both rails | sum of the above |
| Tx | inter-tile UART out | signal |
| Rx | inter-tile UART in | signal |

so the *minimum* is 5 nets, but HV and GND want more than one contact each to actually carry the current (most small contacts are ~1–2A apiece), so realistically **~6–8 contacts per edge**.

### constraints / nice-to-haves (the ones that actually shape this)
- **hotplug-safe**: the whole [power](power.md) scheme is built around mating a tile onto a *live* neighbor (bootstrap + comms live, HV on that edge off until master enables it). the connector has to make/break under power without arcing or shorting adjacent contacts
- **orientation rules (scoped down):** the supported moves are **180° flip of an individual tile** and **90° rotation of the *whole* keyboard as a unit**, NOT 90° of a single tile relative to its neighbors. since a tile is 5×6, that means **only same-length edges ever meet** (a 5un edge mates a 5un edge, a 6un edge mates a 6un edge), never a 5un against a 6un. so:
    - there are really **two edge connectors**: a short one (5un edges) and a long one (6un edges). each only ever mates its own kind.
    - within a kind, every edge still needs the **identical, self-mating connector + pinout**, and the pinout still has to be **symmetric** so a mirrored edge maps power→power and swaps Tx↔Rx (more below). the 180° flip is exactly a mirror, so the symmetry work covers it.
    - whole-keyboard 90° doesn't un-mate or re-mate anything (the whole array turns together), it just changes which USB-C port faces you, already handled by the dual-port thing in [comms](comms.md). so 90° costs the connector nothing.
    - (the hardware-UART side assignment over in [comms](comms.md) isn't an orientation thing, it's just optimizing which sides carry the most traffic toward master, so none of this touches it.)
- **self-aligning + retention**: tiles snap together and stay together; ideally the connector helps hold them
- **low profile**: it's a must-have for the whole board, so the connector can't be a tall stack
- **cheap**: ×4 edges × N tiles, this multiplies fast
- **durable / many mate cycles**: people will reconfigure these a lot

## Brainstorm

### the symmetry thing (this constrains every option)
when tile A's right edge butts against tile B's left edge, A's contacts meet B's contacts *mirrored*. so whatever order i put the nets in has to be a palindrome for power and swap for comms. something like:

```
edge pinout (8 contacts):   GND  HV  BOOT  Tx    Rx  BOOT  HV  GND
neighbor sees it reversed:  GND  HV  BOOT  Rx    Tx  BOOT  HV  GND
                                            └swap┘
```

power/ground land on themselves (palindrome), and Tx lands on the neighbor's Rx / vice-versa, which is exactly what a UART link wants. doubling HV and GND kills two birds: it makes the layout symmetric for free, AND it's the only way to get the current across at all. this pinout requirement applies no matter which connector type i pick, so i'm locking it in up front.

**current note:** with the gender split, each power net has 2 mating contacts (one pogo + one pad in parallel), so each carries half. HV ~4A = ~2A per contact. that's a non-issue, high-current pogos and spring-fingers rated 3–5A+ are cheap and common, so i just spec a contact rated for it. no extra contacts needed.

### connector type options

**A: pogo pins (spring-loaded) + flat pads**
one edge has pogo pins, the mating edge has gold flat pads. springy contacts tolerate a little misalignment and z-height variation, great for hotplug (wiping contact), no insertion force to speak of.
- + hotplug-friendly, self-cleaning wipe, tolerant of slop, low profile-ish
- + cheap-ish per pin
- − they wear, and they need *something else* (magnets?) for retention since they only push apart
- + self-mating is handled by the half-pogo/half-pad gender split (see below), so the usual "pins-on-one-edge-pads-on-the-other" headache doesn't apply here

**B: magnetic pogo (pogo + magnets for alignment & retention)**
same pogo contacts but with magnets doing self-alignment + holding the tiles together (think laptop magnetic chargers / a lot of modular gadgets). magnet polarity can also enforce correct orientation.
- + everything pogo has, plus retention + snap-together feel + self-alignment for free
- + polarity keying can physically prevent mating something backwards
- + inherits the same self-mating gender split as plain pogo, so no gender headache
- − magnets cost money and add a little height/weight, ×4 edges
- − magnets near the hall sensors?? need to check they don't mess with key sensing (the keys are literally magnetic hall switches). probably fine if far enough / shielded but FLAG THIS, it's the scary one

**C: board-to-board mezzanine / hirose-style**
precision plug + socket.
- + tons of contacts, solid signal integrity, compact
- − needs exact alignment, fragile, real insertion force, not made for blind hotplug or repeated reconfig, and plug≠socket so same self-mating problem but worse. probably not it for a snap-together board

**D: card-edge (PCB edge into a slot connector)**
the tile's own PCB edge is the contact, mates into an edge-card slot on the neighbor.
- + dirt cheap (contacts are just PCB), durable-ish
- − a slot is bulky + has insertion force + is directional, doesn't snap/hotplug nicely, and orientation-agnostic is hard. eh

**E: spring-finger / leaf contacts (one edge sprung, other flat pads)**
like pogo but flat leaf springs instead of plunger pins.
- + low profile, cheap, wiping contact
- + a wide beam is solid metal end to end, so current per contact is actually as good as or better than a small pogo
- + the gender split works here too (sprung half / pad half), so self-mating is fine, same as pogo
- − less Z-travel than a pogo plunger, so fussier about tiles sitting coplanar

### the self-mating problem: split the gender down the middle
the "this edge is male, that edge is female" asymmetry is what fought "every edge identical." the fix falls right out of the palindrome: make **half the contacts pogo (male) and half flat pad (female), split exactly at the center**. so on the 8-contact edge:

```
contact:  1     2    3     4    5    6     7    8
net:      GND   HV   BOOT  Tx   Rx   BOOT  HV   GND
gender:   pogo  pogo pogo  pogo pad  pad   pad  pad
```

because contact `i` always meets the neighbor's contact `9−i` (mirror), the male half of one edge lands exactly on the female half of the other. every pair checks out, right net AND opposite gender:
- GND↔GND, HV↔HV, BOOT↔BOOT on the power contacts (palindrome handles the net)
- Tx(pogo)↔Rx(pad) and Rx(pad)↔Tx(pogo) on the comms pair (swap is what UART wants)

so **every edge of a given length is self-mating**: any 5un edge mates any 5un edge, any 6un edge mates any 6un edge, no bridge piece, no separate male/female tile variants. two footprints total (short + long), each repeated on its two edges. this is the whole thing clicking into place :3

### retention: separate job from the contacts
the pogo contacts only push apart, they don't hold anything, so keeping tiles stuck together is its own problem. my original plan was **bigger magnets baked into the case walls** along each edge, doing the holding (and some self-alignment) totally independent of the electrical contacts. i like this because:
- the holding magnets can sit out at the case wall, away from the key area, which keeps them away from the hall sensors (the scary interaction)
- the connector stays a dumb genderless pogo strip, no magnets in the contact itself
- big magnets = strong hold, instead of relying on tiny in-connector ones

on the hall-sensor worry: a case magnet is a *static* DC field, and per-key min/max calibration already absorbs DC offset (noted on the [hall-effect-sensors](hall-effect-sensors.md) page). so as long as the case magnet doesn't *saturate* the sensor, the offset just calibrates out. that downgrades it from "scary" to "keep the magnet far enough away and check it doesn't rail the sensor." still need to actually measure it, but it's not a dealbreaker.

i still want to score the alternatives instead of just defaulting to my plan, so retention gets its own table below.

## Select

### contact mechanism
(retention is scored separately, so magnetic-pogo's magnets aren't counted here, just the contact itself. so "pogo" covers both plain and magnetic pogo.)

| Criteria | Weight | Pogo + pad | Mezzanine | Card-edge | Spring-finger |
| --- | :----: | :---: | :---: | :---: | :---: |
| Hotplug-safe make/break under power | 9 | 9 | 3 | 4 | 8 |
| Current per contact | 7 | 7 | 8 | 6 | 8 |
| Self-mating / genderless (with the split trick) | 8 | 9 | 2 | 3 | 8 |
| Low profile | 7 | 7 | 6 | 8 | 9 |
| Cost (×4 edges × N tiles) | 7 | 6 | 4 | 9 | 7 |
| Durability / mate cycles | 6 | 7 | 5 | 7 | 6 |
| Alignment tolerance | 5 | 8 | 3 | 5 | 7 |
| **Weighted total** | |  **375** | 214 | 288 | **375** |

**It's a tie: pogo + pad and spring-finger both land at 375 / 490 (76.5%).** 

the two really differ on just two axes:
- **pogo wins on Z-axis compliance:** the plunger has real travel (~0.5–2mm), so it forgives tiles not sitting perfectly coplanar (warp, slop, an uneven desk). a spring-finger deflects less, so it's fussier about the gap staying consistent.
- **spring-finger wins on profile + cost:** it's flatter and basically free to stamp.

mezzanine and card-edge stay out (neither likes blind hotplug or genderless mating).

**leaning pogo, but barely, and only for the Z-compliance.** modular tiles that get pulled apart and snapped back a lot are exactly where coplanarity drifts, and pogo travel eats that. but spring-finger is a real co-winner, not a fallback: if a prototype shows pogo height fighting the low-profile goal, switching costs nothing in the scoring. **this one wants a physical prototype of both to break the tie for real.**

### retention

| Criteria | Weight | Case-wall magnets | In-connector magnets | Mechanical latch | Friction / none |
| --- | :---: | :---: | :---: | :---: | :---: |
| Holding strength | 8 | 8 | 7 | 9 | 3 |
| Keeps magnets away from hall sensors | 8 | 8 | 3 | 10 | 10 |
| Self-aligning help | 6 | 6 | 9 | 4 | 3 |
| Low profile / not bulky | 6 | 7 | 6 | 4 | 9 |
| Cost | 5 | 6 | 5 | 6 | 9 |
| Snap-together feel / hotplug | 6 | 8 | 9 | 5 | 3 |
| Doesn't complicate the genderless connector | 5 | 9 | 6 | 7 | 8 |
| **Weighted total** | | **329** | 279 | 295 | 279 |

**Winner: case-wall magnets (329 / 440, 74.8%)** - which is the plan i walked in with, but now it's earned. it holds well, keeps the magnets clear of the sensors, and leaves the connector dumb. mechanical latch (295) scores well on holding + zero magnet risk but loses on bulk + snap feel + reconfig friction. in-connector magnets self-align best but park magnets right next to the hall sensors, the one thing i'm trying to avoid.

## decision
> **superseded in part** - the contact *mechanism* below still stands, but the physical realization changed completely. see [revisit](#revisit-i-picked-a-real-connector-and-it-killed-the-custom-cutout-idea) at the bottom: it's an off-the-shelf 6P connector pair now, not loose pogo pins, and the pinout grew from 8 contacts to 12.

- **contacts:** leaning pogo + flat pad (genderless via the center gender split), but it's a true tie with spring-finger, decided only by pogo's Z-compliance. spring-finger is a live co-winner if low-profile gets tight. **prototype both before committing.**
- **retention:** magnets baked into the case walls, separate from the contacts
- **pinout:** the palindrome (GND HV BOOT Tx Rx BOOT HV GND), power doubled, split pogo/pad down the middle
- **two variants:** short (5un) and long (6un) edges, like only ever mates like

### still open (carry forward)
- actually measure a case magnet's field at the nearest hall sensor, confirm it doesn't saturate
- ~~pick a real pogo part + magnet size once i'm doing the case + board outline~~ - **pogo part picked**, see revisit. magnet size still open.

## Revisit: i picked a real connector, and it killed the custom-cutout idea

### what i was about to build

i'd gone a long way down a rabbit hole. the plan was **individual discrete pogo pins** (Top-Link 10101012662) mounted into a **negative cutout routed into the board edge**, so the pin body lives *inside* the 1.6mm board thickness and adds zero Z-height. the contact side would be a **plated scallop** - a half-hole castellation routed at depanelization - giving the plunger a concave cradle of matched radius instead of a flat pad, so Hertzian contact spreads over a patch instead of a point.

it was a genuinely nice idea and the physics checked out. i worked through most of it:
- **0mm gap between tiles** makes working height = cutout depth, which drops the pin's own ±0.15mm length tolerance out of the stack entirely
- **advance = cavity depth `t`, not radius `R`**, so conformity (R) and protrusion (t) are independent knobs - `protrusion = 0.80 + t`, `pocket depth = 3.50 − t`
- landed on a ⌀1.5mm hole (R=0.75), t=0.40mm, 3.15mm pocket, 1.20mm protrusion

### why it died

none of the physics was wrong. what killed it was everything *around* the physics:

- **it's an unproven custom footprint, hand-soldered, ×40.** four edges × ~10 pins × however many tiles, every one of them a hand-placed pin in a routed slot. if the footprint is off by the 0.13/−0.08mm JLC gives me on holes plus ±0.1mm on routing, i find out forty joints in.
- **the tolerance stack was load-bearing and i'd already been wrong once.** i misread the pin drawing and told myself the body was ⌀1.54 when only the mid-lip is; i under-reported plunger protrusion as 0.85mm when the ⌀1.5 half-hole and its shallower pocket actually make it 1.55mm. two errors on the same part in one sitting is the design telling me something.
- **the scallop is a depanelization artifact.** it only exists because the plated hole gets routed through when the board leaves the panel, which means its finish quality is a process side-effect, not a spec i can order. and a routed vertical edge can't take hard gold (that's a top/bottom-face service) - so it's **ENIG's 0.05–0.1µm** on a surface designed to be *rubbed*, versus 0.75–1.27µm on a real wear finish.
- **i was designing a connector.** that's a solved problem someone else has already tooled.

### the part

**PG-6P-2.5-5.5H-SM-RA**, Shenzhen Yiwei Technology. 6 positions, 2.5mm pitch, 5.5mm height, surface-mount, right-angle. **Two per side: one 6P male + one 6P female.**

**and the gender split falls out for free.** the whole "split the gender down the middle" trick above - the thing that made every edge self-mating - is now just *place two bodies per edge, male one side of the midline and female the other.* i don't have to engineer it, it's two parts. the cleverest bit of the original design became the least clever bit of the implementation, which is exactly what you want.

### the gender rule: clockwise, male first

the one thing that is **not** obvious, and that i'd get wrong if i wrote it down lazily as "male on the left half": *left* stops meaning anything once the edge rotates. the actual invariant is rotational.

**going clockwise around the tile perimeter, every edge is male-then-female.**

| edge | traversed clockwise | first body | second body |
| --- | --- | --- | --- |
| top | left → right | J1 **male** | J2 female |
| right | top → bottom | J3 **male** | J4 female |
| bottom | right → left | J7 **male** | J8 female |
| left | bottom → top | J5 **male** | J6 female |

and *that's* why it self-mates. when tile A's right edge butts against tile B's left edge, they're the same physical line, but A and B traverse it in **opposite** rotational senses - A's clockwise runs top→bottom along it, B's clockwise runs bottom→top. so A's male half is at the top and B's male half is at the bottom, which means A-male lands on B-female and A-female lands on B-male, everywhere, automatically. the 180° flip case falls out the same way.

it's the same trick as the palindrome, just applied to gender instead of nets, and it only reads correctly if you state it as a rotation.

### the pinout, now 12 contacts

```
contact:  1    2    3    4    5    6   |   7    8    9    10   11   12
net:      GND  GND  HV   HV   BS   Tx  |   Rx   BS   HV   HV   GND  GND
body:     <-------- 6P male -------->  |  <------- 6P female ------->
pin:      1    2    3    4    5    6   |   1    2    3    4    5    6
```

so per body, and this is what's actually drawn: **male = GND GND HV HV BS Tx** on pins 1–6, **female = Rx BS HV HV GND GND** on pins 1–6.

mirror check, contact `i` meets the neighbor's contact `13−i`:

| pair | nets | gender |
| --- | --- | --- |
| 1 ↔ 12 | GND ↔ GND ✓ | male ↔ female ✓ |
| 2 ↔ 11 | GND ↔ GND ✓ | male ↔ female ✓ |
| 3 ↔ 10 | HV ↔ HV ✓ | male ↔ female ✓ |
| 4 ↔ 9 | HV ↔ HV ✓ | male ↔ female ✓ |
| 5 ↔ 8 | BS ↔ BS ✓ | male ↔ female ✓ |
| 6 ↔ 7 | **Tx ↔ Rx** ✓ | male ↔ female ✓ |

**4× GND, 4× HV, 2× BS, Tx, Rx.** power doubled from the original 8-contact sketch (which had 2 HV / 2 GND), because two 6P bodies hand you twelve contacts whether you want them or not and spending the extras on copper is the obvious move.

**GND stays outboard**, exactly like the original `GND HV BOOT Tx Rx BOOT HV GND` sketch had it - i just doubled each pair rather than reordering. that ordering is worth keeping deliberately: the outermost contacts are the ones most exposed to debris, misalignment and a partially-inserted tile, and those should be **ground, not a 20V rail**. HV sits inboard behind them, and the comms pair sits dead centre where it's most protected.

> ⚠ **superseded.** putting GND at the extremes necessarily puts Tx/Rx furthest from any ground return - measured, **10.0mm** - which caps the link well below the PIO's ~18.75 Mbaud. reordered to `GND HV HV BS Tx GND` in [the revisit below](#revisit-gnd-outboard-was-the-wrong-principle---it-should-be-gnd-flanking). same counts, same palindrome, GND still on 1 and 12.

> **footprint rule, and it's the one that breaks everything if you get it wrong:** both bodies must be placed **symmetric about the edge midline**. the contacts don't need uniform 2.5mm spacing *across* the male/female boundary - the two bodies will have their own end margins, so that gap will be wider than 2.5mm - they only need to mirror. identical bodies butted symmetrically about center gives that automatically. an asymmetric placement silently maps HV onto Tx.

### what this does to the rest of the design

- **the per-side current budget finally exists.** 4× HV contacts at 1A each = **4A hard ceiling per side**, and i'm designing the switch for **≥2A continuous** (50% contact derate). that closed the question that had been blocking the HV per-side FET choice since the research flagged it as *"the single biggest lever"* - working through in [power schematic-design](../schematic-design/power.md#hv-per-side-switches---picking-the-fet). the FET went **AO3401A → AO4407A** as a direct result.
- **2A supports the array sizes i care about:** ~18W at 9V (≈3.6 tiles downstream), ~40W at 20V (≈8 tiles). at 9V the connector's 4A ceiling is the real limit rather than the voltage - 36W ≈ 7 tiles.
- **the "~6–8 contacts per edge" estimate in Identify was low**, and the "each power net has 2 mating contacts... HV ~4A = ~2A per contact" note is stale - it's 4 contacts at 1A now. leaving both as the record.
- **no inset sequencing.** with loose pins i could have recessed the signal contacts so they broke first on unplug. two molded bodies can't do that - each body carries HV, GND *and* signal, so there's no way to split them by depth. **all twelve contacts make and break together.** that means hot-unplug safety rests entirely on the PD voltage, not on ordering.

### the voltage consequence

pogo voltage ratings are **arc-erosion** specs, not dielectric ones (the magnetic connector i looked at earlier rates 36VDC but withstands 500VAC). what actually matters on a hot break is the **minimum arcing voltage** of the contact metal: gold is **~15V**. below that a sustained arc physically cannot form, regardless of current. that's a floor, not a derating.

and it's not just voltage - **an arc needs a minimum voltage AND a minimum current**, both. for gold that's **~15V and ~0.4A**. miss either one and it can't sustain.

> **correction: 12V was the wrong default.** i'd written this around 12V, but **12V isn't a required PD voltage** - the USB PD Power Rules make the steps above 5V **9V (27W) / 15V (45W) / 20V (60W)**. 12V is never required at any power level, it's an optional extra PDO. a source may simply not offer it. so the plan can't be built on it.

redoing it against the steps that actually exist:

| PD step | vs V_min (15V) | per-tile draw | verdict |
| --- | --- | --- | --- |
| **9V** | below | 0.56A | **unconditionally safe** - the voltage axis alone blocks it, current doesn't matter |
| **15V** | *at* the threshold | 0.33A/tile | safe **only when breaking ≤1 tile** (0.33A < 0.4A). 2 tiles = 0.67A → can arc |
| **20V** | above | - | not arc-safe |

**!firmware-note!** so the standing plan is **firmware defaults to 9V**, and that's a stronger result than the 12V version it replaces - 12V was safe with ~3V of room, 9V has 6V, and it doesn't depend on how much is downstream. 15V turns out to be conditionally safe in a way that's nearly useless: it only holds for a single-tile break, which is exactly the case i don't care about. 20V stays behind an explicit flag with a "don't hot-unplug" warning.

**what 9V costs:** 2A × 9V = 18W ≈ **3.6 tiles** per joint, down from 5 at 12V. the connector's 4A ceiling gives 36W ≈ 7 tiles. so at 9V the array is **current-limited rather than voltage-limited**, which is one more reason the [per-side FET](../schematic-design/power.md#hv-per-side-switches---picking-the-fet) needed to be the one with current headroom.

**and one to actually check on the bench:** [session 2](../schematic-design/log.md) records that the TPS54302 *"can't make 5V below ~9V in"*, so **9V is exactly the buck's stated minimum input**. the safest arc voltage is also the tightest buck condition. that's a measurement, not an assumption.

### risks i'm carrying knowingly

- **single-source niche part.** it isn't in the LCSC/JLC catalogue at all (i searched). that's *fine* because these are hand-soldered - a constraint the original decision quietly assumed but never wrote down - but it means no second source and no JLC assembly for this line. buy spares.
- **5.5mm height vs "low profile", which is a stated must-have.** this is taller than the 4.00mm magnetic connector i partly rejected on bulk, so i should be honest that i'm not applying the criterion evenly. the argument for why it's OK: it's a right-angle part at the board perimeter, below switch height, and the thing it actually has to clear is the case wall - not the key stack. **needs checking against the real case cross-section**, not hand-waved.
- **populate 2 tiles first.** 40 hand-soldered connectors on a footprint that has never been built is not where i want to discover a 0.2mm error. validate the joint on one mating pair before committing the rest.

### still open

- price + stock, once i've actually ordered
- confirm 5.5mm clears the case wall on the real cross-section
- magnet size for retention (unchanged from above)
- draw the two footprints (short 5un / long 6un edge) with the symmetric-about-midline rule baked in

## Revisit: GND outboard was the wrong principle - it should be GND *flanking*

### what prompted it

comms is spec'd at **≥4 Mbaud** and the PIO can theoretically do **~18.75 Mbaud** (8 cycles/bit at 150MHz). i wanted to know what stops me taking it. the answer isn't the PCB - it's this connector, and it's a consequence of the ordering i chose two sections up for a completely different reason.

measured off the as-drawn footprint:

```
J1 male:  GND  GND  HV   HV   BS   Tx        pitch 2.5mm
                                   ^
          Tx pad -> nearest GND pad:  10.00 mm
```

**Tx and Rx are the two contacts furthest from a ground return in the whole connector.** that fell straight out of "GND outboard" - putting ground at the extremes necessarily puts the comms pair at the other end from it.

### why 10mm matters at 18.75 Mbaud and not at 4

the return current for Tx has to travel 10mm laterally through the connector body before it finds a ground pin. that's a loop, and a loop is an inductor:

```
L ~ (u0/pi) * l * ln(d/r)      l = 5.5mm connector height, r ~ 0.5mm pin
   d = 10.0mm  ->  6.6 nH
   d =  2.5mm  ->  3.5 nH        (logarithmic, so 4x closer is only ~2x better)

bounce = L * di/dt,  3.3V into ~50R in ~2ns  ->  di/dt ~ 3.3e7 A/s
   6.6 nH  ->  0.22 V
   3.5 nH  ->  0.12 V
```

**at 4 Mbaud this is invisible** - a 250ns bit sampled mid-bit doesn't care about 220mV of ringing that settles in nanoseconds. at 18.75 Mbaud the bit is **53ns**, and 0.22V is ~7% of the swing injected at the seam, on a signal that then has to survive the neighbouring tile's identical version of it.

### the new pinout

```
contact:  1    2    3    4    5    6   |   7    8    9    10   11   12
net:      GND  PD   PD   BS   Tx  GND  |   GND  Rx   BS   PD   PD   GND
body:     <-------- 6P male -------->  |  <------- 6P female ------->
```

mirror check, contact `i` meets contact `13−i`:

| pair | nets | |
| --- | --- | --- |
| 1 ↔ 12 | GND ↔ GND | ✓ |
| 2 ↔ 11 | HV ↔ HV | ✓ |
| 3 ↔ 10 | HV ↔ HV | ✓ |
| 4 ↔ 9 | BS ↔ BS | ✓ |
| 5 ↔ 8 | **Tx ↔ Rx** | ✓ |
| 6 ↔ 7 | GND ↔ GND | ✓ |

**still a palindrome, and the counts are identical: 4× GND, 4× HV, 2× BS, Tx, Rx.** nothing is traded away in current capacity - this is pure reordering.

### the version i nearly settled for, and why this one is better

the obvious move was `GND HV HV BS GND Tx` - just slide one ground next to Tx. that fixes the return path and passes the palindrome. but it leaves **Tx at 6 and Rx at 7, directly adjacent across the seam with nothing between them**, which is full-duplex near-end crosstalk between the two signals i care most about.

putting the ground *inboard* of the signal instead gets both:

| | Tx → nearest GND | Tx ↔ Rx |
| --- | --- | --- |
| as drawn (GND outboard) | 10.0mm | adjacent |
| `…BS GND Tx` | 2.5mm | **adjacent** |
| **`…BS Tx GND`** ✅ | **2.5mm** | **7.5mm, two grounds between** |

and it means the two bodies meet **GND-to-GND at the seam**, which is the widest gap in the whole run.

### what this costs, said plainly

**"GND outboard" is dead as a principle.** the [original reasoning](#the-pinout-now-12-contacts) was that the outermost contacts see debris, misalignment and partial insertion, so they should be ground rather than a 20V rail. that's still true, and **positions 1 and 12 are still GND** - the single most exposed contact on each end is unchanged.

what changes is that **HV moves from position 3 to position 2**, so the 20V rail is now 2.5mm from the exposed end instead of 5mm. that's a real reduction in the exposure margin and i'm taking it deliberately.

the replacement principle is stronger, not weaker: **GND outermost *and* flanking the signals.** it satisfies the original safety argument at the extremes and adds a return path where the original had none.

### this alone doesn't get me to 18.75 Mbaud

the pinout halves the bounce. the other half is **`R84`–`R87`, which are currently 0Ω placeholders** - populating them at **22–33Ω** makes them proper source-series termination, damping the reflection at the driver *and* slowing di/dt:

| | bounce | Tx↔Rx |
| --- | --- | --- |
| today | 0.22 V | adjacent |
| new pinout only | 0.12 V | 7.5mm, shielded |
| **new pinout + 33Ω series** | **~0.05 V** | **7.5mm, shielded** |

**neither alone is enough; both together are.** and the 33Ω is worth doing regardless of whether i ever chase 18.75 Mbaud - it's free, it's already a placeholder, and it helps the crosstalk-into-analog problem that every fast digital net on this board has.

### carry-forward

- **8 connector instances** (J1–J8) need the new pin assignment in the schematic - and the [gender rule](#the-gender-rule-clockwise-male-first) has to survive it unchanged, since it's rotational and independent of net order
- **[chips](../chips.md)** quotes the old `GND GND HV HV BS Tx | Rx BS HV HV GND GND` string
- **R84–R87 → 22–33Ω**, and they stop being placeholders
- if i take 18.75 Mbaud, the inter-tile UARTs move from Tier C to Tier A in [the layout checklist](../layout-checklist.md#appendix---every-net-ranked) and probably want adding to the `Switching` netclass so the 0.5mm analog-separation rule covers them

if reading by stream of consciousness go back to [index](../index.md)

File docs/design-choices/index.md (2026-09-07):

# Design choices

`Revisited`{.status .revisited}

Read these roughly in order - each one constrains the next, and several get
reopened later once a downstream decision proved them wrong.

## The shape of the thing

1. [Form factor](form-factor.md) - **Modular 5×6 ortho tiles** (won't be a simple build)
2. [Switches](switches.md) - **Void Switch-based custom switch** (low-profile modified Void Switch, analog hall effect)
3. [Feature decisions](feature-decisions.md) - Submodules, per-key RGB, FIDO 2, no bluetooth, no AUX port

Those three together produce the MCU requirements, which is what the next
section is answering.

## Picking the parts

4. [Controller (MCU)](controller.md) - RP2350B with the option to populate a second 16MB flash chip
5. [Key sensors & MUX](hall-effect-sensors.md) - GH39F for sensor, 74HC4067 for mux · *revisited twice*
6. [RGB](rgb.md) - SK9822-EC20 · *revisited*
7. [Submodules](submodules.md) - 4-pin (5V/GND/Rx/Tx) per corner · *revisited*
8. [Power](power.md) - really complicated power flow · *re-decided*
9. [Communications](comms.md) - PIO UART inter-module, independent UART per corner · *revisited ×3*

## Does it fit

10. [Pin budget](pin-budget.md) - 44/48 GPIO, 6/8 ADC, 12/12 PIO SMs · *corrected*
11. [Module connectors](module-connectors.md) - *revisited ×2*
12. [PCB stackup & net rules](pcb-stackup.md) - **4-layer** (sig/GND/pwr/sig)

---

Pages marked *revisited* / *corrected* contain reasoning that was later found
wrong. It's kept rather than deleted - the dimmed blocks are the original
thinking, with a link to what replaced it.

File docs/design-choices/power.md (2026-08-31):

# Power management and Inter Module connections
# Identify
I need to decide on how i am going to do power distribution

### Relevant constraints/nice to haves:

#### Must haves
- Portable

#### Nice to haves
- Per-key RGB (under-glow)

#### Nice to have, but harder to achieve
- Have submodules

### Design rules

**!firmware-note!** **80% rule - firmware enforced:** firmware never draws more than 80% of the negotiated PD capacity from any port. This applies to the total allocated power budget across all tiles in a region. Consequences that flow from this:
- A 100W port (20V @ 5A) is treated as 80W (20V @ 4A) available to spend
- Components on the HV path (backfeed diodes, switches) are sized to the 80% current ceiling, not the port's rated max
- RGB brightness caps, submodule power limits, and multi-port load balancing all operate against the 80% budget, not the raw negotiated wattage

### Load budget

| Load | Worst case (5 V) | Notes |
| --- | --- | --- |
| RGB | ~360 mA (SK6812) / ~540 mA (SK9822) | dominant; full-white, firmware-capped in practice |
| Hall sensors | ~270 mA | GH39F 9 mA × 30; less if bank-powered |
| RP2350B + misc | ~50–100 mA | |
| Submodules | ~500 mA but probably per assembled keyboard, not per module | (will probably implement submodule power useage estimation in firmware) |
| **Per tile total** | ~1.41A (or 0.91 x # of modules +0.5) | worst case |

## Brainstorm

### PD, or not
I am going to need USB-PD to work at full capacity, there is no question. With a power budget of 1.41A per module, i need it to be able to produce 5V@1.75A (per 80% rule) from the 'high voltage' coming from the PD.

**Idea #1 (going with this cuz its one of those 'all the other ideas are kinda stupid and immediately dismiss-able so they aren't even worth writing down'):** design against the worst possible event, a 8x8 module setup (you could probably run doom on the RGB with that). im not planning on designing it to *support* 64 modules, but it would like it to *work*, just be highly discoraged.

64 modules is ~300W max draw, no way to power that off 1 USB-PD port, so it needs to support multiple ports and share. The flow:
PD capability of plugged in port (what voltages and current) → PD Chip → RP2350B → Master RP2350B
Then the master consolidates whatever voltage gives the most power, tells the system to pick that voltage, remembers how many watts it can 'spend', and if there isn't enough power it limits things like RGB. The PD voltage gets its own dedicated line between modules that each module bucks down itself.

What it requires:
- USB-PD chip the MCU can control
- buck converter for 5V from the high voltage line
- a high voltage line running across the whole keyboard

**Idea #2:** uhhh, no PD, just deal with the lack of power and limit the LEDs.

Going with **Idea #1** because it's a lot more fun to implement and actually lets the keyboard be fully utilized. (Idea #2 isn't really a separate design anyway, it's just what #1 does when a port can't supply enough.)

### The 3 power systems (rails)
Keeping the noisy stuff off the sensitive stuff:
- **Clean rail** (3.3V) for the MCU + hall sensors + MUX, LDO'd off bootstrap so the buck and RGB noise doesn't mess with the analog sensor readings
- **Bootstrap** (5V, always on) so every tile can boot and handshake before high voltage is allowed on
- **Noisy rail** (LED + submodule) off each tile's local buck from the high voltage line, where ripple doesn't matter

### Independent vs linked control
**Linked** (one always on, the other always off):

| | State 0 | State 1 |
| --- | --- | --- |
| High voltage | off | on |
| Bootstrap | on | off |

**Independent:**

| | State 0 | State 1 | State 2 | State 3 |
| --- | --- | --- | --- | --- |
| High voltage | off | on | off | on |
| Bootstrap | on | off | off | on |

Going **independent, bootstrap always on**. i was worried about state 3 (both on), but that's only a problem if both 5V sources feed the same net, and they don't: the MCU/clean stuff is on bootstrap and the heavy stuff is on the local buck. So both being on is just the normal running state, not something to avoid.

Reasons i'm not doing the linked/complementary thing (bootstrap off when HV on):
- it breaks hotplug. a new tile needs bootstrap to boot and handshake, but if the system already turned bootstrap off it can't onboard anything new without dropping back to the boot state
- handing the MCU's power from bootstrap over to the local buck mid-run risks a brownout glitch
- the only upside (bootstrap not carrying MCU current once HV is up) only matters at like 64 tiles. at a normal ~6 tiles it's like 0.5A, who cares

### Per-side control
High voltage gets a switch per side (4x). that's what lets me do the partition thing instead of paralleling PD sources (each source owns its own region at its own voltage, boundary switches stay open), plus it gives me per-side fault isolation and the ability to power one neighbor on/off at a time. Each switch is an e-fuse / soft-start, so it also handles inrush into the buck input caps and gives per-tile overcurrent protection for free.

Bootstrap does NOT get per-side switches: it's always on and spans every side because it has to reach everything for the handshake/hotplug. GND also spans everywhere (never partitioned, everything needs a shared reference), and comms spans the whole board too so one master can still run the show even when power is split into regions.

(this adds 4 HV-enable GPIO per tile, noting it for the pin budget)

> **Correction - "boundary switches stay open" is only half an isolation.** A single MOSFET is a **unidirectional** switch: its intrinsic body diode sits across source–drain, the gate has no control over it, and with the switch wired source-on-PD+ / drain-on-connector it blocks **outbound** only. Inbound current from a neighbour flows straight through the diode regardless of whether my switch is on.
>
> The partition scheme still works, but **cooperatively** - both sides of a boundary have to be open, and then the two body diodes oppose each other and the edge net genuinely floats. What's *not* true is that a tile can unilaterally refuse power from a neighbour that has decided to send it. Two PD sources at different voltages still can't fight (that case has both boundary switches open by definition), so the architecture holds - the mechanism is just "both agreed" rather than "either can veto".
>
> Not being fixed: true bidirectional blocking needs back-to-back FETs and a gate drive referenced to a floating shared source, to defend against a firmware topology bug. Full working, including the firmware teardown requirement it creates, in [power schematic-design](../schematic-design/power.md#the-body-diode---an-open-switch-only-blocks-outbound).

### Buck setup
The buck has to source from the HV rail, not just the local PD chip, so a tile with no USB port can still make its own 5V off the incoming high voltage. Leaning toward 2 bucks: a small always-on one for bootstrap/clean, and a big gated one for the HV->5V heavy loads.

### Bootstrap: where it comes from + OR'ing
Bootstrap isn't pushed from one place. every powered tile feeds it locally:
- **pre-HV:** the cabled tile's raw VBUS 5V (USB gives 5V by default before any PD negotiation, which is what powers the MCU + PD chip + comms so they can even handshake)
- **post-HV:** every tile makes its own 5V off the HV rail (its clean buck) and ideal-diode OR's that onto the shared bootstrap net (ideal-diode, NOT a plain schottky, the drop is too much on 5V)

So in steady state bootstrap is sourced locally at every tile, not shoved from one buck across the whole array (kills the IR-drop / one-buck-carries-everyone worry).

Hotplug falls right out of this: plug a tile onto a running neighbor and it gets bootstrap 5V straight from that neighbor's local buck (across the bootstrap pin), boots, asks the master for power over comms, master enables HV to it, then it starts making its own 5V and feeding bootstrap too. The edge it mates to has live bootstrap + comms but dead HV (that side's switch is still off), so plugging in is safe.
(this needs comms to handle dynamic join + adjacency detection, not just one-time startup discovery. noting it for the comms page)

### Startup + inrush
The dangerous window is before PD negotiates: i only have ~1.5A at 5V, so if a bunch of tiles all wake at the same instant the inrush can sag/collapse the rail and deadlock before i ever reach negotiation. Fix: per-tile soft-start on the bootstrap input, and keep the pre-PD load to just MCU + comms (no RGB/submodules).

Why per-tile/ripple HV enable does NOT work for startup: the big inrush is the global 5V->20V ramp (one source raising the whole connected rail), which sequencing can't stage, and enabling tiles one-by-one onto an already-live rail just dips it each time. So the move is: pre-connect the tree at 5V (low energy) then ramp once. Per-side enable earns its keep on topology/fault/hotplug, not startup inrush.

Order:
1. plug in, VBUS = 5V (USB default, no negotiation yet)
2. raw 5V gets OR'd onto the bootstrap rail and spans the network, every MCU + comms boots
3. master discovers topology over comms (HV still off)
4. master closes the HV tree switches while everything is still at 5V (low-energy connect)
5. as VBUS ramps past ~6V, the hardware comparator fires: VBUS→bootstrap switch opens AND VBUS connects to the local HV rail simultaneously. the tile's clean buck spins up from HV and feeds bootstrap back almost immediately - hold-up caps only need to cover the microseconds in between. no firmware involvement.
6. negotiate PD up to ~20V. VBUS + the whole HV rail ramp 5V->20V together, PD slew limits the inrush
7. each tile's bucks now make their own 5V from HV (clean buck -> MCU/sensors + bootstrap, big buck -> RGB/submodules)
8. master turns loads on within the negotiated power budget

Multi-port version: step 4 is "enable HV per region from each source", a tree per source instead of one global enable.

### Why HV partitions but bootstrap combines
The thing that makes the whole scheme click:
- **HV = partitioned.** different PD sources negotiate different voltages (20V vs 15V vs whatever). tie those together and the higher one dumps into the lower one, so HV regions have to stay separate (boundary switches open).
- **Bootstrap = combined.** every tile's buck puts out the *same* 5V no matter what its HV input is, so OR'ing them just makes a stronger 5V, there's no voltage mismatch to fight. the bucks normalize everything to 5V, which is exactly what lets bootstrap be one shared net even when HV is chopped into regions.
- **GND = common everywhere.** always. everything needs a shared reference.

The ideal diodes do the rest: highest source conducts, the others stand by, they droop-share if the load grows, and a short on one tile just opens its own diode/e-fuse without dragging down the net. So combining bootstrap isn't a problem, it's a feature: redundancy + local sourcing + per-tile fault isolation.

### Still open (parts + details)
- exact PD chip: needs MCU control, so a FUSB302-class PD PHY, not a fixed-request HUSB238
- buck + ideal-diode controller + e-fuse part numbers
- backfeed/OR'ing protection on each PD input for the multi-port case
- whether to bother rippling the pre-PD bring-up or just lean on per-tile soft-start

### How the power flows (revised)

#### The rails
- **Bootstrap (5V, always on, shared):** powers every MCU + comms, so tiles can boot and handshake before HV exists.
- **HV (negotiated PD voltage, ~20V, per-side switched):** the distributed high-voltage line. partitionable into per-source regions.
- **Clean 3.3V (LDO off the local 5V):** MCU + hall sensors + MUX, kept away from the noisy stuff.
- **GND:** common everywhere.

#### Per tile
- USB-C + PD chip (only actually used on a tile with a cable plugged in)
- hardware comparator watching VBUS: below ~6V → VBUS feeds bootstrap; above ~6V → VBUS disconnects from bootstrap and connects to local HV rail instead, clean buck immediately takes over bootstrap
- small "clean" buck (HV -> 5V) for the clean rail, ideal-diode OR'd onto bootstrap
- big buck (HV -> 5V) for RGB + submodules
- 3.3V LDO off the clean 5V for the MCU + sensors
- 4x per-side HV switches (e-fuse / soft-start)

#### Startup
1. plug in -> VBUS is 5V (USB default, no negotiation yet)
2. raw 5V -> bootstrap net -> every MCU + comms boots
3. master discovers the layout over comms (HV still off)
4. master closes the HV tree switches while everything is still at 5V (low-energy connect)
5. as VBUS ramps past ~6V, the hardware comparator opens the VBUS→bootstrap switch automatically (bootstrap holds on its caps)
6. negotiate PD up to ~20V; the whole HV rail ramps 5V -> 20V, PD slew limits the inrush
7. each tile's bucks now make their own 5V from HV: clean buck -> MCU/sensors (and feeds bootstrap), big buck -> RGB/submodules
8. master turns loads on within the negotiated power budget

#### Steady state
- every tile self-powers off HV through its own bucks
- bootstrap is one shared 5V net fed by every tile's clean buck (ideal-diode OR'd): redundant and locally sourced
- HV is partitioned per PD source, GND is common

#### Hotplug
plug a tile onto a running neighbor -> it gets bootstrap 5V + comms from that neighbor (HV on that edge is still off, so it's safe to mate) -> boots -> asks the master for power -> master enables HV to that side -> the tile self-powers and joins in.

#### The rule that makes it work
HV **partitions** (sources are different voltages, can't mix), bootstrap **combines** (the bucks make them all the same 5V, so OR'ing is fine), GND is **common**.

### What chips are actually needed

#### USB-PD PHY
Needs to: take orders from the RP2350B, negotiate any PD profile (not just a fixed list), and report back what the port can actually supply. The MCU has to be in the loop because the multi-port power budget logic lives in firmware.

**Options:**
- **FUSB302BMPX**: I²C, handles both source and sink roles, RP2350B runs the full PD state machine in firmware. Open-source stacks exist for RP2040 that should port to RP2350 cleanly. QFN-24, ~$0.60 at LCSC.
- **STUSB4500**: has its own NVM and can negotiate without MCU involvement, but that fights with the multi-port budget logic where the MCU *needs* to be in the loop. Also slightly more expensive.
- **CH224K / HUSB238**: fixed-request, no MCU control, already ruled out.

#### Small clean buck (HV → 5V, always on)
Needs to: take HV (5–20V input - has to work from the moment VBUS arrives at 5V, before PD negotiates up) and output a stable 5V for the LDO. Load is just MCU + sensors (~150–300mA). Doesn't need to be ultra-quiet itself since the LDO is downstream. Must run always-on (MCU and comms need it).

**Options:**
- **MP2161GJ-Z** (MPS, 2A, SOT-23-5, ~$0.20 LCSC): cheap, very common, 2A gives headroom on a ≤300mA load, ~1.5 MHz.
- **RT8272AGSP** (Richtek, 2A, SOT-23-5, ~$0.15 LCSC): same class, slightly cheaper. Good sourcing fallback if MP2161 goes out of stock.
- **TPS62130** (TI, 3A, VQFN): more capable but bigger and pricier. Overkill here.

#### Big buck (HV → 5V, gated)
Needs to: handle RGB + submodule load (~2A worst case per tile), with 5–20V input range. Can be off until HV is up and loads are enabled. Noise on this rail doesn't matter.

**Options:**
- **MP2315GJ-Z** (MPS, 3A, SOT-23-8, ~$0.30 LCSC): 3A at low cost, the standard pick for keyboard RGB supplies. Very commonly stocked at LCSC.
- **SY8113ADC** (Silergy, 2A, SOT-23-5, ~$0.15 LCSC): cheaper but 2A ceiling is tight against worst case. Fine only if firmware always caps RGB current below ~1.5A per tile.

#### 3.3V LDO (clean analog rail)
Needs to: be low-noise (this feeds the ADC + hall sensor chain), handle ~200–300mA (RP2350B + bank-powered sensors), be small.

**Options:**
- **XC6220B332MR** (Torex, 300mA, SOT-23-3, ~$0.10 LCSC): low noise, 300mA headroom, tiny. Right fit for a clean analog supply.
- **XC6206P332MR** (Torex, 200mA, SOT-23-3, ~$0.05 LCSC): same family, cheaper, but 200mA is tight if bank-powered sensor current peaks higher than expected. Fine if sensor power-gating is confirmed solid in firmware.
- **AMS1117-3.3** (800mA, SOT-223): works and it's everywhere, but noisier and physically large. Last resort only.

#### Ideal diode (bootstrap OR'ing, one per tile)
Needs to: OR each tile's clean 5V output onto the shared bootstrap net with near-zero forward drop. ~1A per tile is sufficient. Can't be a plain Schottky - 0.3–0.5V drop on a 5V rail is too much.

**Options:**
- **MAX40203** (ADI, integrated ideal diode, 1A, SOT-23-3, ~$0.40 LCSC): no external FET, handles it all internally, tiny. 1A is comfortable at typical clean buck bootstrap contribution per tile.
- **LM74700QDBVRQ1** (TI, ideal diode controller, SOT-23-6) + external P-FET: more flexible and handles higher currents, but doubles part count per tile. Upgrade path if 1A turns out to be tight.
- Schottky: no.

#### VBUS → bootstrap switch + HV connect

This is handled entirely in hardware with a comparator doing double duty. A comparator watches VBUS with a threshold at ~6V (between the 5V pre-negotiation level and the 9V lowest PD voltage). It drives two things simultaneously:
- **VBUS→bootstrap switch opens** - disconnects VBUS from bootstrap before it can climb past 5V
- **VBUS→HV rail connects** - routes VBUS directly onto the local tile's HV rail

The second action is the key improvement: the tile's clean buck immediately sees HV input and starts making 5V, which feeds bootstrap right back. Bootstrap never actually droops - the hold-up caps only need to cover the few microseconds between the comparator firing and the buck spinning up, not any meaningful hold time. This also means a second cable hotplugged into a running tile self-powers that tile's HV rail and restores bootstrap instantly with no firmware involvement.

**Implementation:** one comparator (TLV1805 or similar, SOT-23-5, ~$0.15) watching VBUS against a resistor-divider reference at ~6V drives:
- A P-FET (AO3415 or similar, 20V/4A, SOT-23) for the VBUS→bootstrap path - gate pulled to GND by default (on), comparator pulls high (off)
- An N-FET or dedicated switch for the VBUS→HV path - off by default, comparator turns it on

No MCU GPIO involved.

*Note: AO3415 is 20V rated - fine for the bootstrap switch because VBUS is only at 5V while that switch is conducting. The HV-path switch needs to be rated for the full negotiated voltage (≥24V).*

#### HV per-side switches (×4 per tile)
Needs to: switch the HV rail (~9–20V) between neighboring tiles, provide soft-start to protect downstream buck input caps from inrush, allow OCP (hardware or firmware), and be MCU-enable controlled. Must be rated ≥24V (20V + ~20% margin) and handle ≥3A (covering a region of multiple tiles, not just one tile's local load).

This is the hardest slot - ">24V + ≥3A + soft-start + cheap + small" is awkward in the integrated eFuse market.

**Options:**

| Option | Part | Cost/switch | Pros | Cons |
| --- | --- | --- | --- | --- |
| Integrated eFuse | TPS1663 (TI, 60V, 3.5A, SOIC-8) | ~$1.50 | OCP, soft-start, fault flag built in | $6/tile at ×4, SOIC-8 is large |
| Discrete (P-FET + RC soft-start + sense R) | 30V+ P-FET + passives | ~$0.25 | cheap, small, flexible, 30V+ P-FETs easy to find | no automatic hardware OCP; firmware OCP via ADC instead |

#### Backfeed protection (multi-port case)
The per-side HV switches handle most of this: boundary switches stay open, so two PD sources at different voltages can't fight over the same HV region. The remaining risk is two USB-C ports plugging in on adjacent tiles simultaneously before the MCU has sorted out topology. Fix: a series blocking element on each VBUS→HV path so neither port backfeeds into the other. A Schottky diode is fine here (this is the HV rail, not 5V, so 0.3V drop is irrelevant).

#### Pre-PD bring-up: don't bother rippling
Per-tile soft-start on the bootstrap input covers inrush during the pre-PD 5V window. The pre-PD window is short, and staged bring-up would need extra sequencing logic for marginal gain. Lean on per-tile soft-start, which is already in the design.

## Select

### USB-PD PHY

Hard gate first: must give the MCU full real-time visibility into PD capabilities and control over negotiation. Fixed-request chips (HUSB238, CH224K) cannot feed the multi-port power budget logic and are not scored.

| Criteria | Weight | FUSB302BMPX | STUSB4500 |
| --- | :---: | :---: | :---: |
| MCU control / real-time negotiation | 10 | 10 | 5 |
| Multi-port budget integration | 9 | 9 | 4 |
| Open-source firmware (RP2040 family) | 7 | 9 | 5 |
| Cost | 5 | 8 | 5 |
| LCSC availability | 5 | 8 | 6 |
| Package / PCB area | 3 | 7 | 7 |
| **Weighted total** | | **345** | **197** |

**Winner: FUSB302BMPX (345/390, 88.5%)**

STUSB4500's NVM-based negotiation trades firmware flexibility for standalone simplicity - the wrong trade for a design where the MCU owns power budget decisions dynamically.

---

### Bucks (clean + big)

**Correction from brainstorm:** MP2161 and RT8272 are eliminated before scoring. Both are rated 18V max; at 80% derating that's 14.4V, well below the 20V HV rail. Using either would be an underated design.

The clean buck must start from the comparator threshold (~5.5V) and run through 20V. The big buck is MCU-gated and only enabled post-PD negotiation (≥9V input), but it still needs to be rated for the full 20V rail it sits on.

**BOM note:** TPS54302 (3A) covers both bucks - the clean buck only draws ~300mA but using one part across both simplifies sourcing and removes a unique BOM line.

| Criteria | Weight | TPS54302 (TI, 4.5–28V, 3A) | MP2315 (MPS, 4.5–24V, 3A) | SY8205 (Silergy, 6–36V, 3A) |
| --- | :---: | :---: | :---: | :---: |
| Input voltage rating (≥21V derated) | 10 | 10 | 5 | 10 |
| Min input ≤5.5V (clean buck startup) | 8 | 9 | 9 | 2 |
| Output current | 7 | 9 | 9 | 9 |
| Cost | 7 | 7 | 9 | 8 |
| LCSC availability | 6 | 7 | 9 | 7 |
| Package / footprint | 5 | 8 | 8 | 8 |
| **Weighted total** | | **366** | **342** | **317** |

**Winner: TPS54302 (366/430, 85.1%), both bucks**

MP2315 (79.5%) fails the voltage rating axis - 24V max derated to 19.2V, below the 20V HV rail. SY8205 (73.7%) has excellent voltage headroom (36V) but its 6V minimum input means the clean buck can't reliably start from the ~5.5V comparator threshold.

---

### 3.3V LDO

Hard requirement: low noise. This rail feeds the ADC chain reading the hall sensors. Ripple here corrupts every keypress measurement.

| Criteria | Weight | XC6220B332MR (300mA) | XC6206P332MR (200mA) | AMS1117-3.3 (800mA) |
| --- | :---: | :---: | :---: | :---: |
| Output noise | 10 | 8 | 9 | 3 |
| Current headroom | 8 | 8 | 4 | 10 |
| Package size | 6 | 9 | 9 | 2 |
| Cost | 6 | 7 | 9 | 9 |
| Dropout voltage | 5 | 7 | 8 | 4 |
| LCSC availability | 5 | 7 | 8 | 10 |
| **Weighted total** | | **310** | **310** | **246** |

XC6220 and XC6206 score identically (310/400, 77.5%). AMS1117 is eliminated by noise and package size (246/400, 61.5%).

**Winner: XC6220B332MR**, selected over XC6206 on engineering judgment: the 100mA difference (300mA vs 200mA) is safety margin against uncertainty in the RP2350B + hall sensor current draw before real hardware measurements. The cost delta (~$0.05/tile) is negligible.

**Revisit:** XC6206 becomes the preferred choice if firmware bank-powering of hall sensors is confirmed and hardware measurements show clean buck current stays under 175mA (20% margin on the 200mA ceiling).

---

### Ideal diode (bootstrap OR'ing)

Plain Schottky is disqualified on hard requirements before scoring - a 0.3–0.5V forward drop on a 5V rail cascades through the LDO headroom budget and is not recoverable. Not scored.

| Criteria | Weight | MAX40203 (integrated, 1A) | LM74700 + external PFET |
| --- | :---: | :---: | :---: |
| Near-zero forward drop | 10 | 9 | 9 |
| Integration / part count | 8 | 10 | 4 |
| Current capacity | 7 | 6 | 9 |
| Cost | 7 | 7 | 5 |
| Package size | 6 | 9 | 5 |
| LCSC availability | 5 | 6 | 7 |
| **Weighted total** | | **345** | **285** |

**Winner: MAX40203 (345/430, 80.2%)**

The 1A ceiling is comfortable for the bootstrap OR'ing load at any realistic tile count. LM74700 + PFET wins on current headroom but doubles part count per tile without justification at this load level. Upgrade to LM74700 + PFET if measured bootstrap current on a real multi-tile board approaches 800mA (80% of 1A ceiling).

---

### HV per-side switches (×4 per tile)

| Criteria | Weight | TPS1663 (integrated eFuse) | Discrete (PFET + RC + sense R) |
| --- | :---: | :---: | :---: |
| OCP speed / reliability | 9 | 10 | 5 |
| Soft-start quality | 8 | 9 | 7 |
| Voltage / VGS headroom | 9 | 10 | 7 |
| Cost per switch (×4/tile) | 8 | 2 | 9 |
| PCB footprint | 7 | 4 | 9 |
| Implementation risk | 6 | 9 | 5 |
| **Weighted total** | | **350** | **329** |

The table favors TPS1663 (350/470, 74.5%) over discrete (329/470, 70.0%), but the margin is narrow and the cost axis does not fully reflect the per-keyboard impact: at ×4 per tile, TPS1663 is ~$6/tile vs ~$1/tile discrete. On a 6-tile board that is $36 vs $6 purely for switching - a meaningful fraction of the $250 total budget.

**Going with discrete** as a deliberate engineering tradeoff: the performance gap is real but the cost and area penalty of TPS1663 locks in $6/tile before any measurements exist to justify it. The failure mode (firmware OCP too slow to catch a fault) is diagnosable on real hardware.

> **Update - the discrete option got much stronger, and this decision was re-run.** Once the connector fixed the per-side current at 4A ceiling / ≥2A continuous, I re-scored this against the actual FET choices in [power schematic-design](../schematic-design/power.md#hv-per-side-switches---picking-the-fet). TPS1663 came second again (329 on that table's scale). The winner is **AO4407A ×4** - the same part already at Q2, so no new BOM line - and crucially its **±25V Vgs** closes the "Voltage / VGS headroom" row that discrete lost 10-vs-7 on here. The AO3401A this table implicitly assumed was ±12V against a 20V rail and only survived because of a zener. So the discrete option now wins that row on merit, not on cost.
>
> **The one thing this decision still owes:** it was made explicitly accepting *"no automatic hardware OCP; firmware OCP via ADC instead."* The current-sense amplifier that makes firmware OCP possible **has never been picked**. Until it is, this table's premise isn't actually implemented.

### Re-decision: does this need per-edge OCP at all?

Went to finally pick the sense amp and ended up questioning whether the whole sensing path earns its place. **It doesn't.**

#### Identify - what am i actually protecting against?

| fault | what covers it *today*, without any sensing |
| --- | --- |
| **dead short across an edge** (debris, shorted neighbour) | **the PD source.** Q4 is ~13mΩ and the contacts/traces are a few more, so the current is set entirely by the source's own limit (~5A for a 60W brick), not by anything on my board. At 5A the AO4407A dissipates **0.33W** - it isn't even warm. The tile browns out until the offending neighbour is removed, then recovers. Unpleasant, not damaging |
| **sustained overcurrent** (too many tiles through one joint) | nothing in hardware - **but firmware already knows the topology.** Master does tile discovery over UART, so it can refuse to enable a path that exceeds the budget, or negotiate a higher PD voltage to cut the current. That's **free**, and it prevents the fault instead of reacting after the contacts have already been at 1.5A |
| **exceeding the connector rating** | already **2× derated** - 2A design target against a 4A connector |

The fast, dangerous fault is bounded by the source. The slow fault is preventable in firmware at zero cost. That's the whole argument.

#### The constraint that actually decides it

This got re-run because **board area is the binding constraint** - the current footprints are already a struggle to place. That kills the obvious hedge (fit the pads, leave them DNP): **a DNP footprint costs exactly as much board as a populated one.** It also reprices everything, because the original discrete-vs-eFuse table above scored **cost** at weight 8 and never scored **area or ADC channels at all**.

ADC is the scarce one. There are **8 ADC total**; 2 go to the key muxes. Per-edge sensing takes **4 more** → 6/8 spent. Dropping it leaves **2/8**.

#### Brainstorm

| | option | area | ADC used | $/tile |
| --- | --- | --- | --- | --- |
| A | 4× INA181A2 (C2058784) + 10mΩ shunts + REF bias | ~95mm² | 4 | ~$1.08 |
| B | 4× TPS1663 eFuse | ~160mm² | **0** | ~$6 |
| C | Footprints fitted, DNP | **~95mm²** | 4 reserved | ~$0 |
| D | **None - firmware topology limiting** | **0** | **0** | **$0** |

#### Select

| Criteria | Weight | A: INA181 | B: eFuse | C: DNP | D: none |
| --- | :---: | :---: | :---: | :---: | :---: |
| Board area (the binding constraint) | 9 | 2 | 3 | 2 | 10 |
| ADC channels left free | 8 | 1 | 10 | 3 | 10 |
| Covers a dead short | 7 | 6 | 10 | 3 | 7 |
| Covers sustained overcurrent | 7 | 9 | 10 | 3 | 8 |
| Cost | 5 | 6 | 1 | 9 | 10 |
| BOM lines / schematic complexity | 5 | 4 | 7 | 8 | 10 |
| Observability for bring-up | 4 | 10 | 5 | 3 | 2 |
| **Weighted total** | | 221 | **307** | 181 | **383** |

**Winner: D, no per-edge current sensing (383/450, 85.1%).**

**C is dominated and that's the finding.** Fitting the footprints DNP costs the same area as populating them and delivers none of the protection - the hedge only ever made sense while i thought area was free.

**And B beat A, which is worth sitting with.** The eFuse scores *higher* than the sense-amp path, because it consumes no ADC. The original table above chose discrete over TPS1663 on **cost**, weight 8 - but the constraints that actually bind on this board turned out to be **area and ADC**, neither of which was on that table. Re-scored honestly: **if this design needed per-edge OCP, the eFuse would now be the right answer, not the sense amp.** It doesn't need it, so D wins outright - but the original decision was right for a reason that has since stopped being the reason.

#### Result

- **No shunts, no sense amps, no footprints.** Not DNP - absent.
- **GPIO42–45 are freed**, ADC budget drops to **2/8**.
- **!firmware-note!** **Firmware owns overcurrent**, by limiting topology *before* enabling a path rather than tripping after. It already has the tile map.
- `INA180` is worth recording as a trap: 71,901 in stock and the cheapest part in the class, and it's **SOT-23-5 with no REF pin** - unidirectional only, which [the body diode finding](../schematic-design/power.md#the-body-diode---an-open-switch-only-blocks-outbound) disqualifies outright. Current flows *inward* whenever a neighbour is sourcing, and a unidirectional amp reads that as zero.
- **What i'm giving up:** bring-up observability. There'll be no way to read per-edge current on real hardware, which is exactly the thing i'd want when something misbehaves. Accepting that deliberately - a bench supply and a meter can do the same job on a prototype, and it doesn't have to be on every tile forever.

## Budget fallback

If the full design BOM comes in way over budget, there's a coherent cheaper version: ditch the per-side HV switches and the bootstrap rail entirely. HV routes directly to each tile's buck converter (TPS54302 handles 4.5–28V, so it runs straight from 5V VBUS before PD even negotiates). No bootstrap needed because the buck IS the bootstrap, every tile self-powers the moment any port gets VBUS.

What you lose:
- **Hotplug safety:** mating a tile onto a live HV rail is uncontrolled inrush, potentially destructive
- **Multi-PD:** two sources at different voltages on the same rail fight each other, stuck to one cable
- **Fault isolation:** overcurrent on one tile can drag down the whole board

Valid design for "assemble flat, plug in one cable, don't touch it while powered." Not for the modular hotplug use case that was a core goal. Keep this as the "it costs HOW much?" escape hatch. The savings are the 4× AO4407A + 4× NPN + the LM66100 ideal diode per tile.

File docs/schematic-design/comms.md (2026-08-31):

# Comms & USB - schematic-design calcs

Datasheet math for the USB front-end and the inter-tile / submodule links. Parts from [chips](../chips.md); behaviour from [comms design-choice](../design-choices/comms.md); the PD/CC re-decision is in [comms revisit](../design-choices/comms.md#revisit-pdcc-architecture-the-cc-mux-doesnt-survive-cold-start).

Values here are **as-built**, with the derivation. Where the independent [datasheet research](../research/README.md) disagrees, both are shown and resolved.

Per-section skeleton: **Goal → Datasheet refs → Math → Result → Notes/gotchas.**

## Contents
- [USB-C receptacles (USB1/USB2)](#usb-c-receptacles-usb1usb2)
- [Cold start: where Rd actually comes from](#cold-start-where-rd-actually-comes-from)
- [Attach inrush - the 10µF problem](#attach-inrush---the-10µf-problem)
- [USB-PD PHY - FUSB302BMPX ×2 (PD1/PD2)](#usb-pd-phy---fusb302bmpx-2-pd1pd2)
- [USB data mux - TS3USB30ERSWR (U2)](#usb-data-mux---ts3usb30erswr-u2)
- [SEL detect - which port wins](#sel-detect---which-port-wins)
- [ESD](#esd)
- [Inter-tile UART lines (not drawn yet)](#inter-tile-uart-lines-not-drawn-yet)
- [Submodule corner UART lines (not drawn yet)](#submodule-corner-uart-lines-not-drawn-yet)

---

## USB-C receptacles (USB1/USB2)

### Goal
Two sink-only receptacles per tile, both orientation-independent, both able to negotiate full PD. USB 2.0 full-speed only - no SuperSpeed, no alt mode.

### Result / as-built pin treatment
| Contact | As-built | Verdict |
| --- | --- | --- |
| A4, A9, B4, B9 (VBUS ×4) | all bussed to one node per port | ✓ required by Table 3-4 Note 2, not optional at 5A |
| A1, A12, B1, B12 (GND ×4) | all to GND | ✓ |
| A5 / B5 (CC1 / CC2) | direct to the port's own FUSB302 | ✓ - see cold-start below |
| A6, B6 (Dp1, Dp2) | **shorted together**, then to the mux | ✓ spec-sanctioned |
| A7, B7 (Dn1, Dn2) | **shorted together**, then to the mux | ✓ |
| A8, B8 (SBU1/2) | open | ✓ correct with no alt mode |
| A2/A3/B2/B3, A10/A11/B10/B11 (TX/RX) | open | ✓ correct for USB 2.0 only |
| SH (shield) | direct to GND | acceptable; see note |

**Shorting Dp1↔Dp2 and Dn1↔Dn2 at the receptacle is the spec's own answer** to orientation independence for a USB 2.0 device (Table 3-4 Note 1), keeping the stub short. It means no active part is needed to make either plug orientation work on data - which matters given this project's history with active parts in the cold-start path.

### Notes / gotchas
- Shield straight to GND is the simple option and fine for a wired desk device. The alternative (resistor + cap bleed to GND) buys EMI/ground-loop flexibility that a single-ended, bus-powered board doesn't obviously need. Leaving as-is.

## Cold start: where Rd actually comes from

This is the thing that killed the CC-mux, so it's worth stating precisely what makes the current design work.

**There are no external 5.1kΩ Rd resistors on this board, and none are needed.** The FUSB302B provides Rd from on-die circuitry, and it does so *before VDD exists*:

- The datasheet specifies **`VUFPDB` ≤ 2.18V max** - "SNK Pull-down Voltage in Dead Battery under all Pull-up SRC Loads" (CC Switches table, p.15). That is a *clamped voltage* spec, deliberately separate from the precision resistance.
- Footnote 5 on the same table: **"RDEVICE minimum and maximum specifications are only guaranteed when power is applied."** The datasheet is explicit about separating "the precise 4.6–5.6kΩ you get once powered" from "what CC does with zero power".
- `Switches0` (0x02) **resets to 0x03 = PDWN1=PDWN2=1** (Table 6, p.21). Both pull-downs are on by hardware reset default, before firmware writes a single I²C byte - so there's no race where firmware has to be fast enough.
- USB Type-C §4.8.5 sanctions exactly this shape of circuit: a clamp rather than a precision resistor is sufficient for a source to recognise a sink and apply VBUS.

Two consequences worth writing down:

1. **2.18V clamped ≈ the ±20% Rd row in Table 4-25**, which the spec says is good for attach detection but *not* guaranteed for reading the source's current advertisement. Once VDD is up, `RDEVICE` is 4.6–5.6kΩ = 5.1k ±10%, which *is* guaranteed for advertisement detection. So: **unpowered → the source turns VBUS on; powered → full 1.5A/3.0A advertisement reading works.** Correct behaviour in both states.
2. **[checklist §6](../schematic-checklist.md) still says "Rd pull-downs on the RP2350B side".** That's left over from the CC-mux design and is wrong now - adding external Rd in parallel with the PHY's own would put ~2.5kΩ on CC and break the advertisement thresholds. **Don't add them.**
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

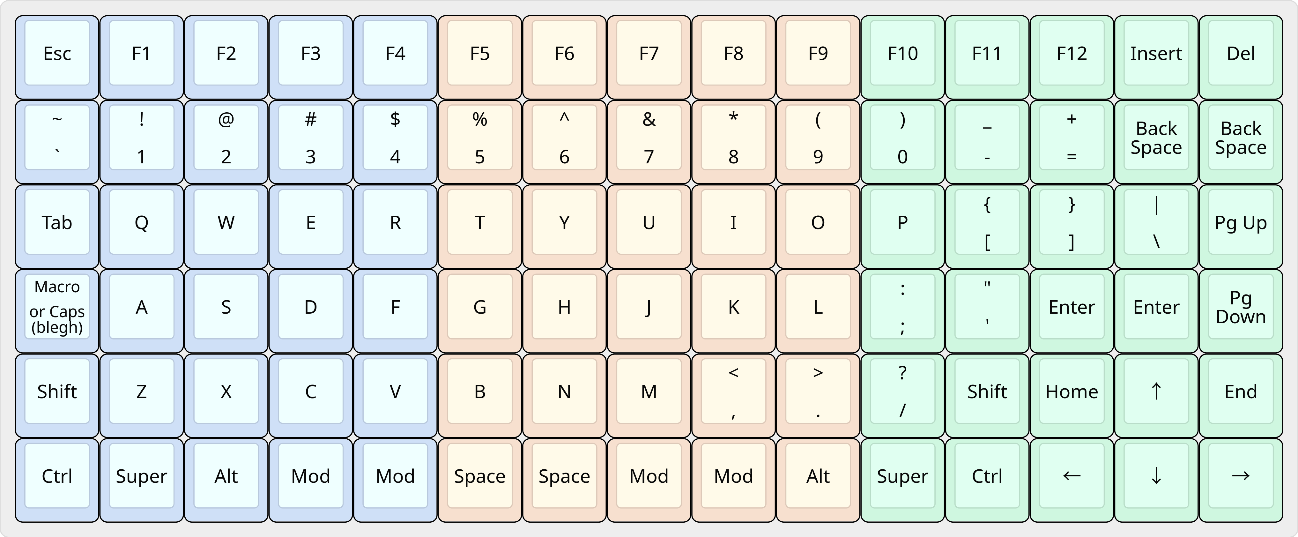
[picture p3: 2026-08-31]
layouts/80-percent.png

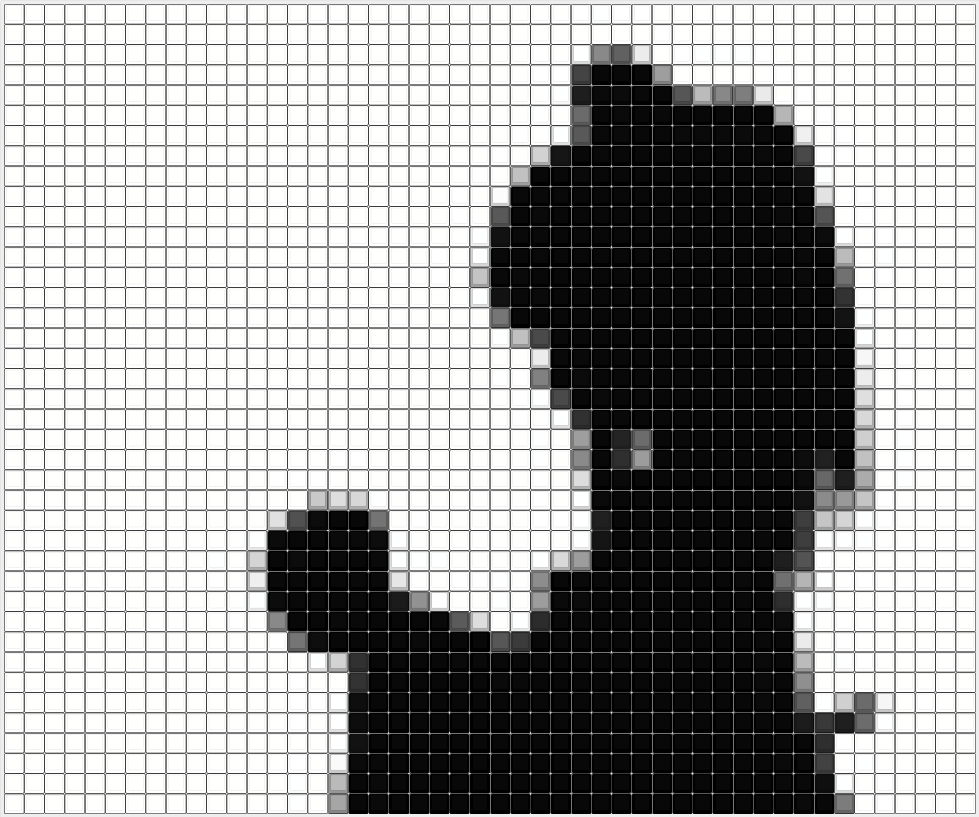
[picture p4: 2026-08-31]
layouts/badapple-percent.png

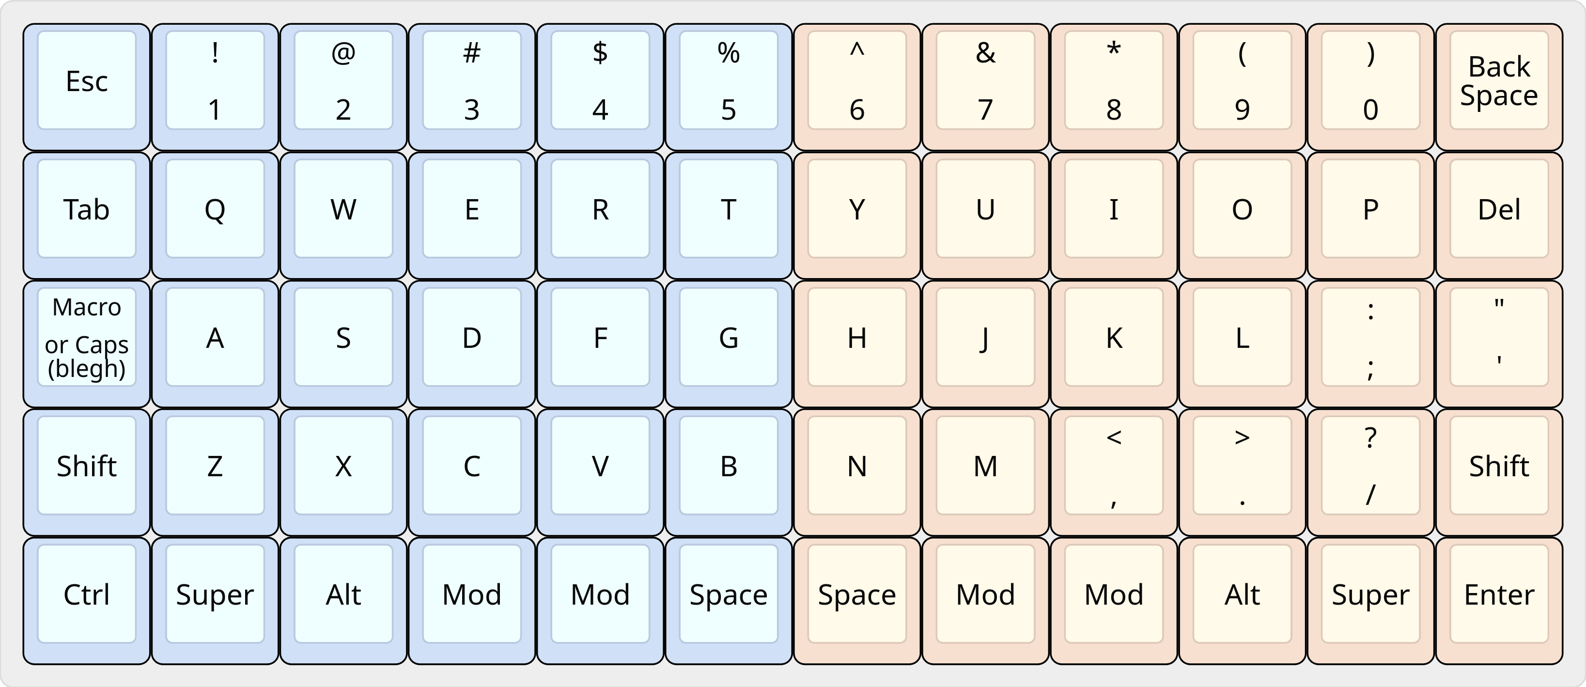
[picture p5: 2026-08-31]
layouts/60-percent.png

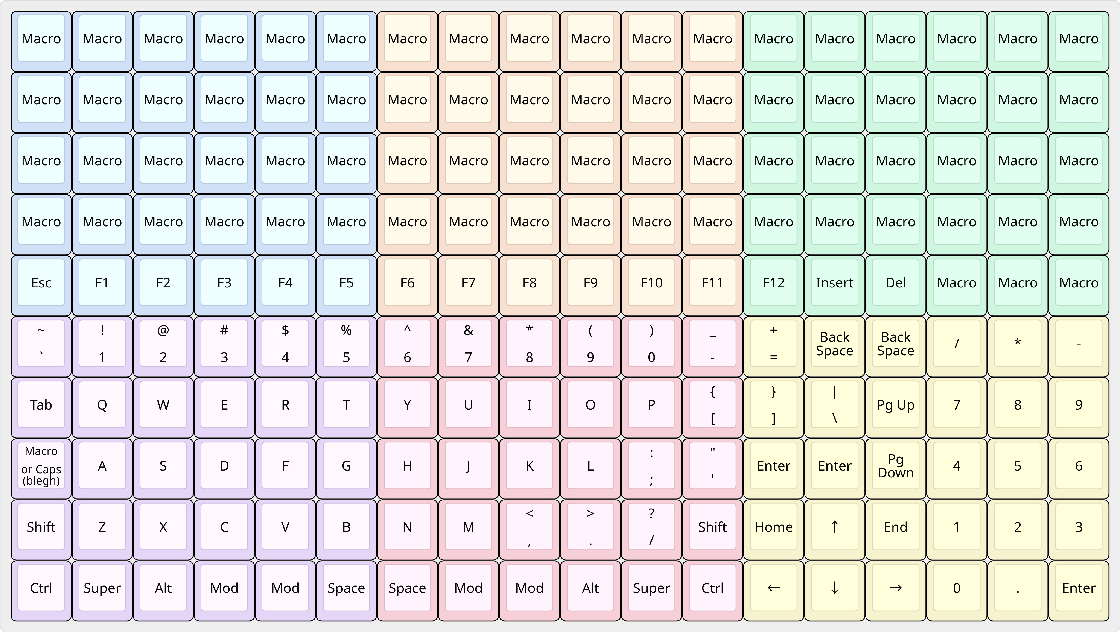
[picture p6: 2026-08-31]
layouts/180-percent.png

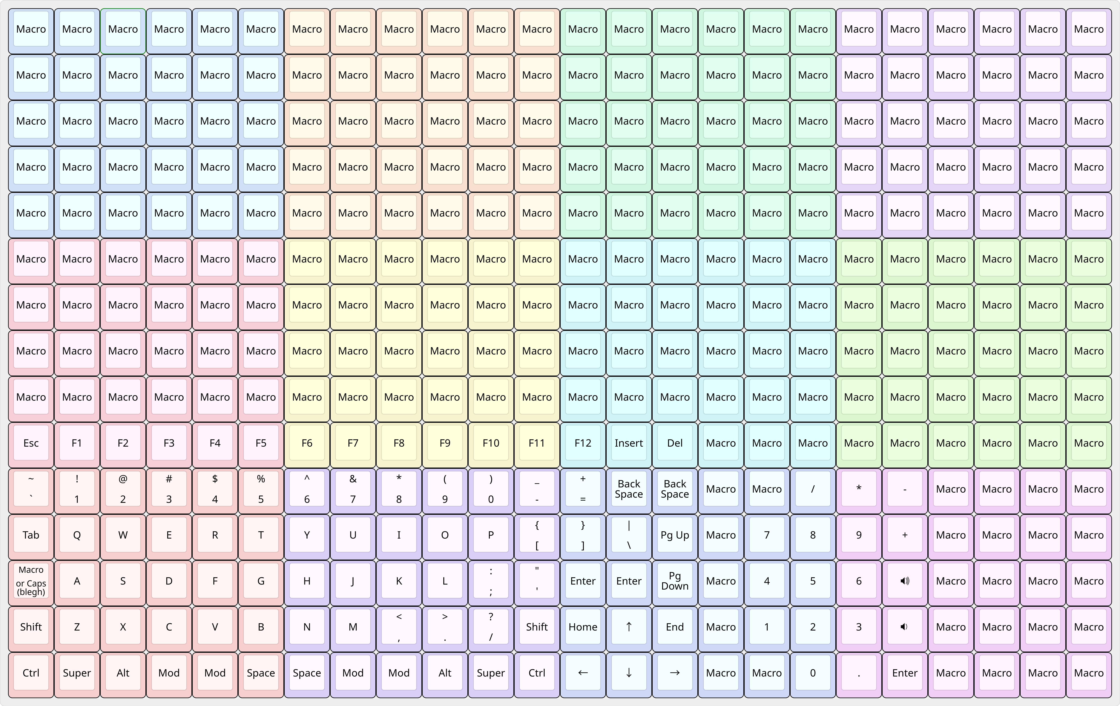
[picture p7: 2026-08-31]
layouts/300-percent.png

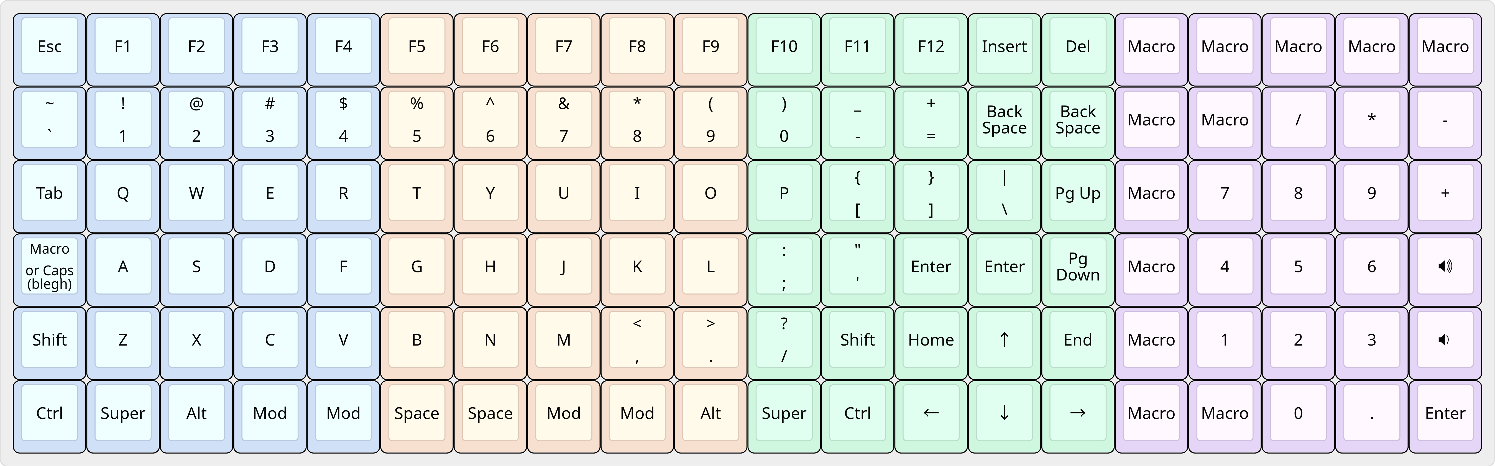
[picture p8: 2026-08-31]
layouts/100-percent.png

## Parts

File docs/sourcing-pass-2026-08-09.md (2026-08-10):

# Sourcing Pass — 2026-08-09

**Scope:** LCSC part-number backfill onto `Voided-Oblivion.kicad_sch`, `power.kicad_sch`, `keys.kicad_sch`.
**Result:** **311 of 373** placed components now carry `LCSC` + `MPN` + `Manufacturer` symbol properties (48 unique LCSC lines: 14 Basic, 4 Preferred, 30 plain-Extended → ~$90 in one-time setup fees). All 48 verified against the JLCPCB catalogue snapshot dated 2026-08-07. Every assigned part has ≥3× the stock needed for a 4-board run — no stock risk remains anywhere in the BOM.

This page records only what is **wrong, blocked, or contradictory**. Everything not listed here checked out.

---

## 1. The previous sourcing pass's results are not in the schematic files

`research/bom-sourcing.md` §*Properties written* and `schematic-design/power.md` §*To do* both record the LCSC/MPN/Manufacturer fields as written. **They are not present in the working files, and never were in any committed revision** (`git show HEAD:…` → 5 `LCSC` properties in `power.kicad_sch`, 0 in the other two).

The work was real and is recoverable as evidence: `Voided-Oblivion-backups/Voided-Oblivion-2026-08-07_210405.zip` contains a `power.kicad_sch` with **83** `LCSC` properties and the `APH0630` inductor assignment. But the schematics inside that zip are the **2026-08-05/08-07 design generation** (root sheet 218 KB vs 382 KB today) — they predate the pogo edge connectors, the submodule ID dividers, U15/U12/U16, and Q4–Q11. Restoring from it would roll the design back, so this pass re-derived the assignments instead and used the backup only as a cross-check on prior intent.

**Consequence:** the review's finding F5 ("MPN coverage 1%") described the files accurately; the two docs above overstate the state of the schematic. Trust the files, not the checkboxes.

---

## 2. `C83711` is 0.75 pF, not 75 pF — a 100× error carried in the docs

`research/bom-sourcing.md` §1 assigns **C83711 / `0402CGR75C500NT`** to **C30 and C36**, described as "75pF, C0G/NP0 50V".

The LCSC listing for C83711 reads **`0.75pF 50V C0G 0402`**. The MPN encodes it: `R75` is the decimal-point form for 0.75 pF; 75 pF would be `750`. The correct Fenghua part is **`0402CG750J500NT` = C37809** (75 pF, 50 V, C0G, ±5%, Extended, 21,458 stock, $0.0012).

This matters: the netlist puts C30 across `U5.FB` and C36 across `U6.FB` — they are the **TPS54302 feedforward capacitors**, i.e. loop compensation. A 0.75 pF part there is a 100× compensation error, not a tolerance nit.

**Action taken:** C30/C36 assigned **C37809**. The wrong number is still printed in `research/bom-sourcing.md` §1 and §8 and should be corrected there.

---

## 3. Footprint/value contradictions — four capacitor groups, nothing assigned

In every case the *previous* design generation had a footprint that worked and the current schematic has a 0402 that cannot. These read as footprint regressions, not new decisions. **No part was forced onto any of them.**

| Refs | Value | Current footprint | Net (from netlist) | Why nothing was assigned | Prior generation |
|---|---|---|---|---|---|
| **C26, C31** | 10 µF | `C_0402_1005Metric` | `PD+` (reaches 20 V) | A catalogue-wide query returns **zero** 10 µF 0402 parts rated above **10 V**. Not a sourcing gap — the part does not exist. | 1206, **C89632** (`CL31B106KBHNNNE`, 10 µF **50 V** X7R) |
| **C28, C29** | 22 µF | `C_0402_1005Metric` | `+5VA` | see below | 1206, **C12891** (`CL31A226KAHNNNE`, 22 µF 25 V X5R, Basic) |
| **C34, C35** | 22 µF | `C_0402_1005Metric` | `+5VP` | see below | 1206, **C12891** |

**On the 22 µF group specifically:** 22 µF 0402 parts *do* exist, but only at **6.3 V and 10 V** X5R (best-stocked: C105226 6.3 V, C3845593 10 V). Neither is usable here. The 6.3 V parts fail derating against a 5.08 V rail outright; the 10 V parts pass derating but lose roughly half their capacitance at 5 V DC bias, which is exactly the failure mode review finding **F13** already called out — the TPS54302 Table 7-2 stability design assumes **44 µF total** per output, and two bias-collapsed 0402s deliver nowhere near that.

So the constraint is not voltage rating, it is DC-bias derating plus loop stability. **The fix is the footprint, not the part number:** restore these four to a 1206 (or at minimum 0805) land and C12891 becomes valid again with no other change. Same for C26/C31 with C89632.

---

## 4. R31 — 12.2 kΩ does not exist on LCSC, at any package, at any tolerance

R30/R31 form the comparator trip divider off `VBUS` (netlist: `R30` VBUS→VDIV, `R31` VDIV→GND). `power.md` requires **0.5 %** here; review **F8** flags the tolerance as unencoded.

- **R30 (44.2 kΩ) — assigned `C2683024`** (`ARG02BTC4422`, Viking Tech, thin film, **±0.1 %**, ±25 ppm/°C, 10,005 stock, $0.022). Judgement call: the only true ±0.5 % 0402 at this value is `C705671` (`RT0402DRD0744K2L`, 113 stock). C2683024 is a *tighter* tolerance, better tempco and ~90× the stock for ~2× the (negligible) unit price, so it satisfies the 0.5 % requirement with margin rather than merely meeting it.
- **R31 (12.2 kΩ) — not assigned.** A direct query of the full catalogue for `12.2k` in the resistor category returns **0 rows**, any package, any tolerance. This confirms `bom-sourcing.md` §6.1: 12.2 k is not an E96 value (E96 has 12.1 k and 12.4 k) and LCSC does not stock the E192 grid at 0402.

**Not substituted, deliberately.** For whoever redoes this: the nearest stocked 0.5 % neighbour is **C4217510** (`RC0402DR-0712K4L`, 12.4 kΩ, ±0.5 %, 10,000 stock). Swapping it moves the trip point from `1.24 × (44.2+12.2)/12.2 = 5.73 V` to `1.24 × (44.2+12.4)/12.4 = 5.66 V` — a **−72 mV** shift against a margin budget the docs put at ~180 mV. That is a real fraction of the budget, so it needs the divider re-derived, not a drop-in.

Practical alternatives unchanged from `bom-sourcing.md`: hand-solder R30/R31 from DigiKey/Mouser (both carry E192 0402 at 0.5 %), or recompute the divider onto a stocked pair.

---

## 5. `C49654456` (49.9 Ω, R18/R24) is gone from the catalogue

The part assigned by `bom-sourcing.md` §2 (`GR0402F49R9TAG00`, GiantOhm, noted there at only 10.0 K stock) returns **not found** in the 2026-08-07 snapshot.

**Replaced with `C140147`** (`RC-02K49R9FT`, Fenghua, 49.9 Ω ±1 % 0402, **145,977 stock**, $0.00067) — same spec, three orders of magnitude more stock. Flagging rather than silently swapping because it changes a line in the published BOM.

---

## 6. L2 / L3 have the part but no footprint

`power.md` §*To do* marks **`[x] L2 = L3 = APH0630T100M`, LCSC `C5349698`, footprint `Inductor_SMD:L_APV_APH0630`** as done. The LCSC assignment has now been written (verified: C5349698, 10 µH, 4.5 A/5.5 A, 68 mΩ, 59,158 stock).

**The `Footprint` field on both L2 and L3 is still empty.** Only the footprint half of that checkbox was lost. Nothing else in this pass depends on it, but it blocks layout and will drop both parts from any position file.

---

## 7. Parts with no LCSC source (expected, listed for completeness)

| Refs | What | Why unsourced |
|---|---|---|
| J1–J8 (8) | `PG-6P-2.5-5.5H-SM-RA` pogo edge connectors | Deliberately off-catalogue, hand-soldered, single-source (Shenzhen Yiwei). Per `chips.md`. Buy spares. |
| J10–J12, J16–J20 (8) | Submodule corner connectors | **Connector body was never chosen.** `design-choices/submodules.md` §*Revision* settles the pinout (5-pin `ID GND 5V Rx Tx`) but closes with "just the connector body to pick later". All 8 symbols have an **empty Footprint field**. No part can be committed until the body is picked. |
| SW1, SW2 | Boot/reset tactile | Footprint is locked to Würth `434133025816`; no match on LCSC. Substituting a generic SMD tactile risks a pad/actuator mismatch. Hand-place, or change the footprint to a JLC-stocked switch. |
| AM0:0–AM1:14 (30) | VoidSwitch key switches | Mechanical, not an LCSC part. Left untouched, as in the prior pass. |
| C22, C37, R1, R11, R13, R28, U4 (7) | DNP placeholders | No intended part. |

---

## 8. Smaller notes

- **Two stock blockers from `bom-sourcing.md` §6 have resolved.** FUSB302BMPX (C132291) is at **6,187** units, not the 627 that prompted the "monitor before ordering" warning. The MAX40203 WLP-4 stock=1 blocker is moot — U9 is now LM66100DCKT (C2832141, 1,123 stock) and U15 is a second instance of the same part.
- **C2841482 is manufactured by UMW, not Alpha & Omega.** `chips.md` and `bom-sourcing.md` both attribute AO4407A/C2841482 to Alpha & Omega; the LCSC listing for that specific number is **UMW (Youtai Semiconductor)**, 105,495 stock. Same MPN and spec (30 V, 9.5 mΩ@10 V, SOP-8) — worth knowing only because it is a second-source house brand. The `Manufacturer` field was written as UMW to match the listing. Note this one number now covers **five** FETs (Q2 + Q4–Q7), not one.
- **Field-name inconsistency fixed.** The 30 hall sensors carried their LCSC number under a field named **`LCSC Part`**, while `power.kicad_sch` used **`LCSC`**. A BOM tool reading `LCSC` would have silently missed all 30. Renamed to `LCSC` on all 30 instances plus the cached library symbol; `MPN` was already correct and `Manufacturer` was added.
- **1 µF moved from 0805 to 0402** (C24, plus new C41/C76/C114/C120). Assigned **C52923** (`CL05A105KA5NQNC`, 1 µF **25 V** X5R, **Basic**, 12.5 M stock) — Basic tier and 25 V, so it clears BS+ at its 5.95 V worst case with wide margin. This replaces the prior 0805 pick C24123 and drops a BOM line.
- **C77 and C121** (10 µF 0402 on the ~5 V `U12.OUT` / `SM+` nodes) were assigned **C315248** (10 V) for consistency with C40 rather than the 6.3 V Basic part. At 5 V bias a 10 V 0402 still derates substantially; these are bulk decoupling on a switch output rather than loop-critical, so it is acceptable — but if either node ever needs a *known* capacitance, size the footprint up rather than the voltage rating.
- **Value-string inconsistencies from `bom-sourcing.md` §7 are unchanged** (`100n`/`100nF`/`0.1µF`, `4.7u`/`4.7µF`, `0`/`0Ω`, Q1's value reading `AO3401` against an `AO3401A` symbol). Sourcing is unaffected — each spelling group resolves to one part — but a literal-text BOM grouper will still split them.

---

## Verification performed

- Paren balance checked on all three files after writing (depth 0, string-aware).
- `kicad-cli sch export netlist` re-parses cleanly; netlist grew 563 KB → 666 KB as the new fields propagate.
- `kicad-cli sch erc` → **1 violation**, unchanged: the intentional `U12.OUT ∥ U15.VOUT` power-OR node (review F3). No regression.
- `kicad-cli sch export bom --group-by LCSC` → 49 grouped rows. **U11 (LM2903, 3 units) groups as a single line**, confirming the multi-unit symbol is counted once.

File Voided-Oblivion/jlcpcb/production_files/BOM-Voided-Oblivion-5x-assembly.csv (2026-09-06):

Comment | Designator | Footprint | LCSC | Quantity
0Ω | R10,R102,R103,R11,R12,R14,R15,R16,R27,R52,R53,R54,R55,R56,R61,R62,R65,R66,R84,R85,R86,R87 | R_0402_1005Metric-no-silkscreen-text | C17168 | 132
100kΩ | R19,R25,R32,R39,R47,R67,R68,R69,R70,R83,R96 | R_0402_1005Metric-no-silkscreen-text | C25741 | 66
100nF | C100,C101,C102,C103,C104,C105,C106,C107,C108,C109,C11,C110,C111,C112,C113,C115,C116,C117,C118,C119,C12,C122,C123,C124,C125,C126,C127,C128,C129,C13,C130,C14,C15,C16,C17,C18,C2,C20,C21,C22,C25,C27,C32,C33,C38,C39,C42,C43,C44,C46,C47,C48,C49,C50,C51,C52,C53,C54,C55,C56,C57,C58,C59,C60,C61,C62,C63,C64,C65,C66,C67,C68,C69,C70,C71,C72,C73,C74,C75,C78,C79,C8,C80,C81,C82,C83,C84,C85,C86,C87,C88,C89,C90,C91,C92,C93,C94,C95,C96,C97,C98,C99 | C_0402_1005Metric-no-silkscreen-text | C307331 | 612
100Ω | R48,R49,R50,R51 | R_0402_1005Metric-no-silkscreen-text | C25076 | 30
10kΩ | R100,R101,R29,R33,R37,R93,R94,R97 | R_0402_1005Metric-no-silkscreen-text | C25744 | 50
10kΩ | R31 | R_0402_1005Metric-no-silkscreen-text | C2902636 | 15
10µF | C121,C19,C31,C40,C77 | C_1206_3216Metric | C89632 | 35
10µH | L2,L3 | L_APV_APH0630 | C5349698 | 12
13.3kΩ | R20,R26 | R_0402_1005Metric-no-silkscreen-text | C2974007 | 20
15p | C3,C4 | C_0402_1005Metric-no-silkscreen-text | C1548 | 20
1MΩ | R35,R46 | R_0402_1005Metric-no-silkscreen-text | C26083 | 20
1kΩ | R2,R23,R36,R4,R5,R6,R98,R99 | R_0402_1005Metric-no-silkscreen-text | C11702 | 50
1nF | C45 | C_0402_1005Metric-no-silkscreen-text | C53547 | 15
1µF | C114,C120,C24,C41,C76 | C_0402_1005Metric-no-silkscreen-text | C52923 | 35
2.2kΩ | R79,R80,R81,R82 | R_0402_1005Metric-no-silkscreen-text | C25879 | 30
20kΩ | R21 | R_0402_1005Metric-no-silkscreen-text | C25765 | 15
22µF | C28,C29,C34,C35 | C_1206_3216Metric | C12891 | 30
27Ω | R7,R8 | R_0402_1005Metric-no-silkscreen-text | C138021 | 20
3.3u | L1 | L_pol_2016 | C42411119 | 7
33Ω | R3,R63,R64 | R_0402_1005Metric-no-silkscreen-text | C138002 | 25
35.7kΩ | R30 | R_0402_1005Metric-no-silkscreen-text | C2681604 | 15
4.7kΩ | R38,R40,R41,R42,R43,R44,R45,R71,R72,R73,R74,R75,R76,R77,R78,R88,R89,R90,R91,R92,R95 | R_0402_1005Metric-no-silkscreen-text | C25900 | 126
4.7µF | C10,C23,C6,C7,C9 | C_0402_1005Metric-no-silkscreen-text | C23733 | 35
4.7µF | C131,C26 | C_0402_1005Metric-no-silkscreen-text | C51205 | 20
49.9Ω | R18,R24 | R_0402_1005Metric-no-silkscreen-text | C140147 | 20
5.1kΩ | R22 | R_0402_1005Metric-no-silkscreen-text | C25905 | 15
75pF | C30,C36 | C_0402_1005Metric-no-silkscreen-text | C37809 | 20
ABM8-272-T3 | Y1 | Crystal_SMD_3225-4Pin_3.2x2.5mm | C20625731 | 7
AO3401 | Q1 | SOT-23 | C15127 | 7
AO4407A | Q2,Q4,Q5,Q6,Q7 | SOP-8_3.76x4.96mm_P1.27mm | C2841482 | 28
AP2171WG-7 | U12,U16 | SOT-23-5 | C110466 | 12
BC847B | Q10,Q11,Q8,Q9 | SOT-23 | C20069135 | 22
BC857 | Q3 | SOT-23 | C20069137 | 7
BZV55B3V3 | D3 | D_MiniMELF | C545375 | 7
BZX84C10 | D4,D5 | SOT-23 | C19077470 | 12
CD74HC4067SM | AM0,AM1 | SSOP-24_5.3x8.2mm_P0.65mm | C98457 | 12
FUSB302BMPX | PD1,PD2 | WQFN-14-1EP_2.5x2.5mm_P0.5mm_EP1.45x1.45mm | C132291 | 12
GH39FKSW | H0:0,H0:1,H0:10,H0:11,H0:12,H0:13,H0:14,H0:2,H0:3,H0:4,H0:5,H0:6,H0:7,H0:8,H0:9,H1:0,H1:1,H1:10,H1:11,H1:12,H1:13,H1:14,H1:2,H1:3,H1:4,H1:5,H1:6,H1:7,H1:8,H1:9 | SOT-23 | C266230 | 165
LM2903 | U11 | JEITA_SOIC-8_3.9x4.9mm_P1.27mm | C7549 | 7
LM66100DCKT | U15,U9 | SOT-363_SC-70-6 | C2832141 | 12
LM74700QDDF | U17,U18 | SOT-23-8 | C3236229 | 12
NCE4009S | Q13,Q14 | SOP-8_3.76x4.96mm_P1.27mm | C189610 | 12
RP2350_80QFN | U1 | RP2350-QFN-80-1EP_10x10_P0.4mm_EP3.4x3.4mm_ThermalVias | C42415655 | 7
SM03B-SRSS-TB | J9 | JST_SH_SM03B-SRSS-TB_1x03-1MP_P1.00mm_Horizontal | C160403 | 7
SN74LVC2T45DCUR | U8 | VSSOP-8_2.3x2mm_P0.5mm | C15741 | 7
TLV431BQDBZR | U10 | SOT-23 | C398374 | 7
TLV76733DRVR | U7 | WSON-6-1EP_2x2mm_P0.65mm_EP1x1.6mm_ThermalVias | C2848334 | 7
TPD2E2U06DRL | U13,U14 | SOT-553 | C1972959 | 12
TPS54302 | U5,U6 | SOT-23-6 | C311983 | 12
TS3USB30ERSWR | U2 | UQFN-10_1.4x1.8mm_P0.4mm | C73880 | 7
USB_C_Receptacle_USB2.0_16P | USB1,USB2 | USB_C_Receptacle_HCTL_HC-TYPE-C-16P-01A | C2894897 | 12
W25Q128JVS | U3,U4 | SOIC-8_5.3x5.3mm_P1.27mm | C97521 | 12
~ | LED1,LED10,LED11,LED12,LED13,LED14,LED15,LED16,LED17,LED18,LED19,LED2,LED20,LED21,LED22,LED23,LED24,LED25,LED26,LED27,LED28,LED29,LED3,LED30,LED4,LED5,LED6,LED7,LED8,LED9 | SK9822-EC20 | C2909059 | 165
~ | SW1,SW2 | SW_SPST_EVQP7C | C388883 | 12

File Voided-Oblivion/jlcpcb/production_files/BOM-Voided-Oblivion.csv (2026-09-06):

Comment | Designator | Footprint | LCSC | Quantity
0Ω | R10,R102,R103,R11,R12,R14,R15,R16,R27,R52,R53,R54,R55,R56,R61,R62,R65,R66,R84,R85,R86,R87 | R_0402_1005Metric-no-silkscreen-text | C17168 | 22
100kΩ | R19,R25,R32,R39,R47,R67,R68,R69,R70,R83,R96 | R_0402_1005Metric-no-silkscreen-text | C25741 | 11
100nF | C100,C101,C102,C103,C104,C105,C106,C107,C108,C109,C11,C110,C111,C112,C113,C115,C116,C117,C118,C119,C12,C122,C123,C124,C125,C126,C127,C128,C129,C13,C130,C14,C15,C16,C17,C18,C2,C20,C21,C22,C25,C27,C32,C33,C38,C39,C42,C43,C44,C46,C47,C48,C49,C50,C51,C52,C53,C54,C55,C56,C57,C58,C59,C60,C61,C62,C63,C64,C65,C66,C67,C68,C69,C70,C71,C72,C73,C74,C75,C78,C79,C8,C80,C81,C82,C83,C84,C85,C86,C87,C88,C89,C90,C91,C92,C93,C94,C95,C96,C97,C98,C99 | C_0402_1005Metric-no-silkscreen-text | C307331 | 102
100Ω | R48,R49,R50,R51 | R_0402_1005Metric-no-silkscreen-text | C25076 | 4
10kΩ | R100,R101,R29,R33,R37,R93,R94,R97 | R_0402_1005Metric-no-silkscreen-text | C25744 | 8
10kΩ | R31 | R_0402_1005Metric-no-silkscreen-text | C2902636 | 1
10µF | C121,C19,C31,C40,C77 | C_1206_3216Metric | C89632 | 5
10µH | L2,L3 | L_APV_APH0630 | C5349698 | 2
13.3kΩ | R20,R26 | R_0402_1005Metric-no-silkscreen-text | C2974007 | 2
15p | C3,C4 | C_0402_1005Metric-no-silkscreen-text | C1548 | 2
1MΩ | R35,R46 | R_0402_1005Metric-no-silkscreen-text | C26083 | 2
1kΩ | R2,R23,R36,R4,R5,R6,R98,R99 | R_0402_1005Metric-no-silkscreen-text | C11702 | 8
1nF | C45 | C_0402_1005Metric-no-silkscreen-text | C53547 | 1
1µF | C114,C120,C24,C41,C76 | C_0402_1005Metric-no-silkscreen-text | C52923 | 5
2.2kΩ | R79,R80,R81,R82 | R_0402_1005Metric-no-silkscreen-text | C25879 | 4
20kΩ | R21 | R_0402_1005Metric-no-silkscreen-text | C25765 | 1
22µF | C28,C29,C34,C35 | C_1206_3216Metric | C12891 | 4
27Ω | R7,R8 | R_0402_1005Metric-no-silkscreen-text | C138021 | 2
3.3u | L1 | L_pol_2016 | C42411119 | 1
33Ω | R3,R63,R64 | R_0402_1005Metric-no-silkscreen-text | C138002 | 3
35.7kΩ | R30 | R_0402_1005Metric-no-silkscreen-text | C2681604 | 1
4.7kΩ | R38,R40,R41,R42,R43,R44,R45,R71,R72,R73,R74,R75,R76,R77,R78,R88,R89,R90,R91,R92,R95 | R_0402_1005Metric-no-silkscreen-text | C25900 | 21
4.7µF | C10,C23,C6,C7,C9 | C_0402_1005Metric-no-silkscreen-text | C23733 | 5
4.7µF | C131,C26 | C_0402_1005Metric-no-silkscreen-text | C51205 | 2
49.9Ω | R18,R24 | R_0402_1005Metric-no-silkscreen-text | C140147 | 2
5.1kΩ | R22 | R_0402_1005Metric-no-silkscreen-text | C25905 | 1
75pF | C30,C36 | C_0402_1005Metric-no-silkscreen-text | C37809 | 2
ABM8-272-T3 | Y1 | Crystal_SMD_3225-4Pin_3.2x2.5mm | C20625731 | 1
AO3401 | Q1 | SOT-23 | C15127 | 1
AO4407A | Q2,Q4,Q5,Q6,Q7 | SOP-8_3.76x4.96mm_P1.27mm | C2841482 | 5
AP2171WG-7 | U12,U16 | SOT-23-5 | C110466 | 2
BC847B | Q10,Q11,Q8,Q9 | SOT-23 | C20069135 | 4
BC857 | Q3 | SOT-23 | C20069137 | 1
BZV55B3V3 | D3 | D_MiniMELF | C545375 | 1
BZX84C10 | D4,D5 | SOT-23 | C19077470 | 2
CD74HC4067SM | AM0,AM1 | SSOP-24_5.3x8.2mm_P0.65mm | C98457 | 2
FUSB302BMPX | PD1,PD2 | WQFN-14-1EP_2.5x2.5mm_P0.5mm_EP1.45x1.45mm | C132291 | 2
GH39FKSW | H0:0,H0:1,H0:10,H0:11,H0:12,H0:13,H0:14,H0:2,H0:3,H0:4,H0:5,H0:6,H0:7,H0:8,H0:9,H1:0,H1:1,H1:10,H1:11,H1:12,H1:13,H1:14,H1:2,H1:3,H1:4,H1:5,H1:6,H1:7,H1:8,H1:9 | SOT-23 | C266230 | 30
LM2903 | U11 | JEITA_SOIC-8_3.9x4.9mm_P1.27mm | C7549 | 1
LM66100DCKT | U15,U9 | SOT-363_SC-70-6 | C2832141 | 2
LM74700QDDF | U17,U18 | SOT-23-8 | C3236229 | 2
NCE4009S | Q13,Q14 | SOP-8_3.76x4.96mm_P1.27mm | C189610 | 2
RP2350_80QFN | U1 | RP2350-QFN-80-1EP_10x10_P0.4mm_EP3.4x3.4mm_ThermalVias | C42415655 | 1
SM03B-SRSS-TB | J9 | JST_SH_SM03B-SRSS-TB_1x03-1MP_P1.00mm_Horizontal | C160403 | 1
SN74LVC2T45DCUR | U8 | VSSOP-8_2.3x2mm_P0.5mm | C15741 | 1
TLV431BQDBZR | U10 | SOT-23 | C398374 | 1
TLV76733DRVR | U7 | WSON-6-1EP_2x2mm_P0.65mm_EP1x1.6mm_ThermalVias | C2848334 | 1
TPD2E2U06DRL | U13,U14 | SOT-553 | C1972959 | 2
TPS54302 | U5,U6 | SOT-23-6 | C311983 | 2
TS3USB30ERSWR | U2 | UQFN-10_1.4x1.8mm_P0.4mm | C73880 | 1
USB_C_Receptacle_USB2.0_16P | USB1,USB2 | USB_C_Receptacle_HCTL_HC-TYPE-C-16P-01A | C2894897 | 2
W25Q128JVS | U3 | SOIC-8_5.3x5.3mm_P1.27mm | C97521 | 1
~ | LED1,LED10,LED11,LED12,LED13,LED14,LED15,LED16,LED17,LED18,LED19,LED2,LED20,LED21,LED22,LED23,LED24,LED25,LED26,LED27,LED28,LED29,LED3,LED30,LED4,LED5,LED6,LED7,LED8,LED9 | SK9822-EC20 | C2909059 | 30
~ | SW1,SW2 | SW_SPST_EVQP7C | C388883 | 2
Sub-Module RB | J19 | 5-pin-machined-female-pin-headers-sunk |  | 1
Sub-Module TL | J10 | 5-pin-machined-female-pin-headers-sunk |  | 1
Sub-Module LB | J17 | 5-pin-machined-female-pin-headers-sunk |  | 1
Bottom female | J8 | PG-6P-2.5-5.5H-SM-RA-Female |  | 1
W25Q128JVS | U4 | SOIC-8_5.3x5.3mm_P1.27mm |  | 1
Sub-Module RT | J20 | 5-pin-machined-female-pin-headers-sunk |  | 1
Right male | J3 | PG-6P-2.5-5.5H-SM-RA-Male |  | 1
Sub-Module BL | J16 | 5-pin-machined-female-pin-headers-sunk |  | 1
Top male | J1 | PG-6P-2.5-5.5H-SM-RA-Male |  | 1
Left male | J5 | PG-6P-2.5-5.5H-SM-RA-Male |  | 1
Right female | J4 | PG-6P-2.5-5.5H-SM-RA-Female |  | 1
Sub-Module BR | J18 | 5-pin-machined-female-pin-headers-sunk |  | 1
Sub-Module TR | J12 | 5-pin-machined-female-pin-headers-sunk |  | 1
Bottom male | J7 | PG-6P-2.5-5.5H-SM-RA-Male |  | 1
Top female | J2 | PG-6P-2.5-5.5H-SM-RA-Female |  | 1
Left female | J6 | PG-6P-2.5-5.5H-SM-RA-Female |  | 1
Sub-Module LT | J11 | 5-pin-machined-female-pin-headers-sunk |  | 1
BOOT | TP36 | TestPoint_Pad_D1.0mm |  | 1
PD1 INT | TP16 | TestPoint_Pad_D1.0mm |  | 1
GND | TP11 | TestPoint_Pad_D1.0mm |  | 1
RUN | TP35 | TestPoint_Pad_D1.0mm |  | 1
PD L | TP25 | TestPoint_Pad_D1.0mm |  | 1
AS3 | TP32 | TestPoint_Pad_D1.0mm |  | 1
SM+ EN | TP27 | TestPoint_Pad_D1.0mm |  | 1
+3V3 | TP6 | TestPoint_Pad_D1.0mm |  | 1
+1V1 | TP7 | TestPoint_Pad_D1.0mm |  | 1
SM+ | TP8 | TestPoint_Pad_D1.0mm |  | 1
PD2 INT | TP19 | TestPoint_Pad_D1.0mm |  | 1
BS+ | TP2 | TestPoint_Pad_D1.0mm |  | 1
AS0 | TP29 | TestPoint_Pad_D1.0mm |  | 1
GND | TP12 | TestPoint_Pad_D1.0mm |  | 1
AS2 | TP31 | TestPoint_Pad_D1.0mm |  | 1
GND | TP10 | TestPoint_Pad_D1.0mm |  | 1
VBUS | TP9 | TestPoint_Pad_D1.0mm |  | 1
AS1 | TP30 | TestPoint_Pad_D1.0mm |  | 1
BS+ SRC | TP3 | TestPoint_Pad_D1.0mm |  | 1
PD T | TP22 | TestPoint_Pad_D1.0mm |  | 1
USB SEL | TP28 | TestPoint_Pad_D1.0mm |  | 1
PD+ | TP1 | TestPoint_Pad_D1.0mm |  | 1
PD1 SCL | TP15 | TestPoint_Pad_D1.0mm |  | 1
+5VP | TP5 | TestPoint_Pad_D1.0mm |  | 1
LED TX | TP34 | TestPoint_Pad_D1.0mm |  | 1
SM BS EN | TP26 | TestPoint_Pad_D1.0mm |  | 1
PD2 SDA | TP17 | TestPoint_Pad_D1.0mm |  | 1
SM BUS | TP37 | TestPoint_Pad_D1.0mm |  | 1
+5VA | TP4 | TestPoint_Pad_D1.0mm |  | 1
PD R | TP23 | TestPoint_Pad_D1.0mm |  | 1
GND | TP13 | TestPoint_Pad_D1.0mm |  | 1
LED SCK | TP33 | TestPoint_Pad_D1.0mm |  | 1
PD1 SDA | TP14 | TestPoint_Pad_D1.0mm |  | 1
5VP EN | TP21 | TestPoint_Pad_D1.0mm |  | 1
PD B | TP24 | TestPoint_Pad_D1.0mm |  | 1
PD2 SCL | TP18 | TestPoint_Pad_D1.0mm |  | 1

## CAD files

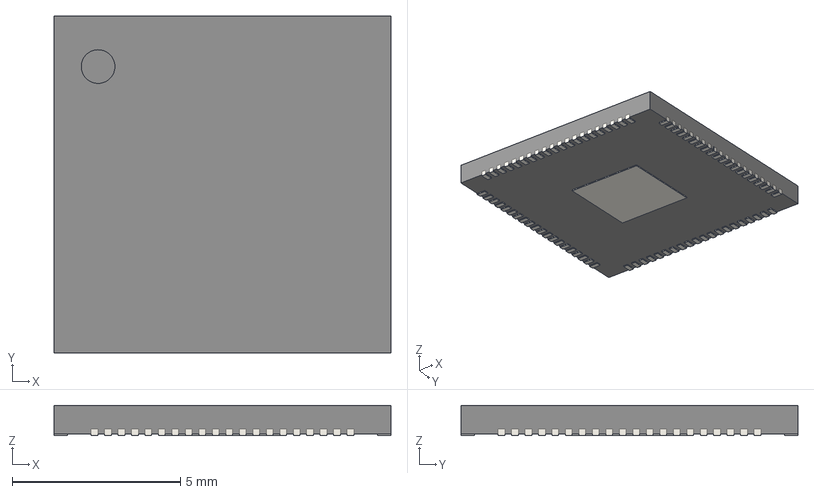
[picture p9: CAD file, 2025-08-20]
footprints/rp2350/RP2350B-QFN80.step
10.0 x 10.0 x 0.9 mm

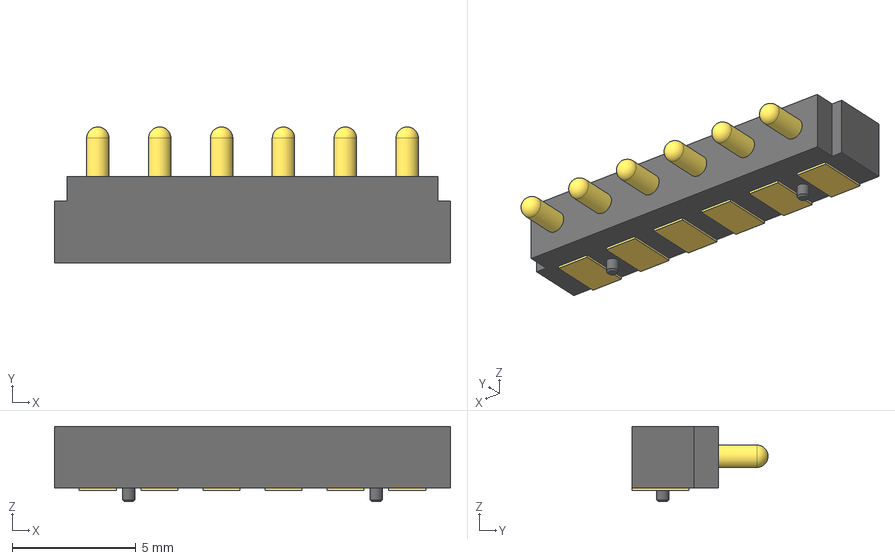
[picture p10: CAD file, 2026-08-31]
Voided-Oblivion/3D-models/PG-2.5-6P-5.5H-SM-RA.step
16.0 x 5.50 x 3.05 mm
pins

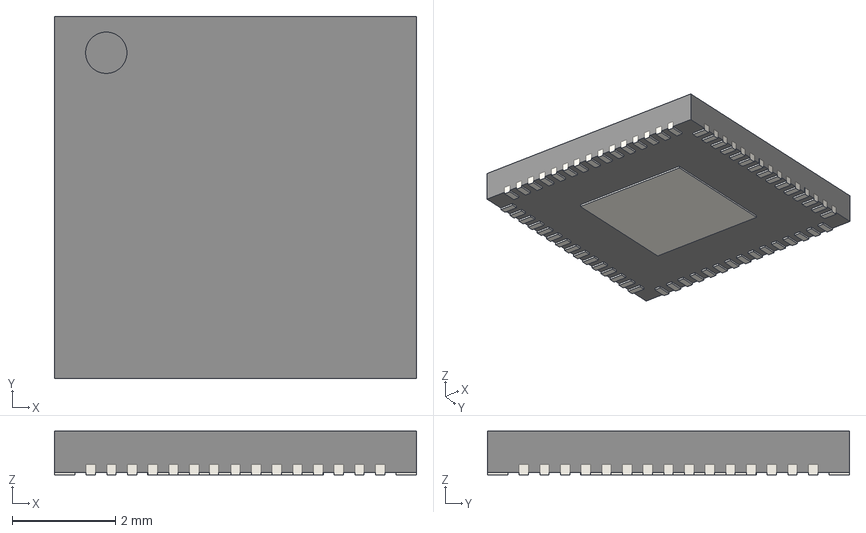
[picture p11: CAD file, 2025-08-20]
footprints/rp2350/RP2350A-QFN60.step
7.00 x 7.00 x 0.85 mm

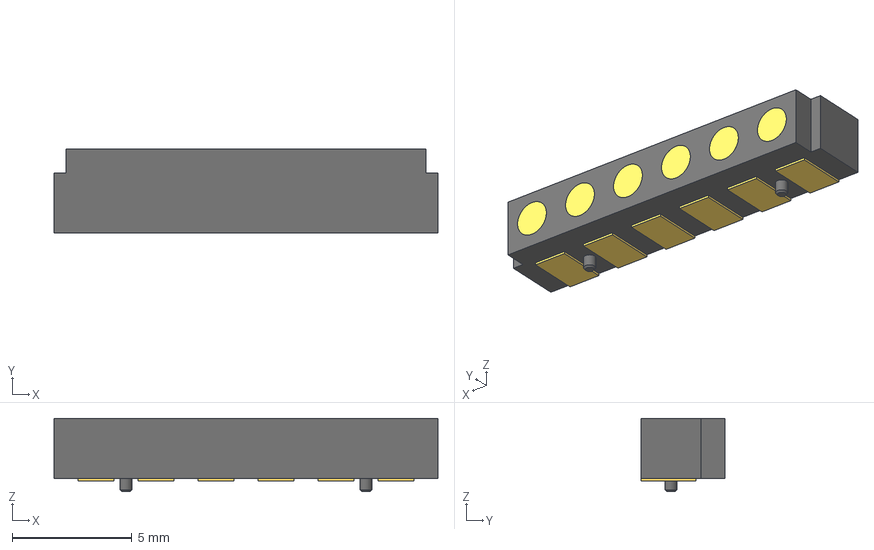
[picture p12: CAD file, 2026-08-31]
Voided-Oblivion/3D-models/PD-2.5-6P-5.5H-SM-RA.step
16.0 x 3.50 x 3.05 mm
pins

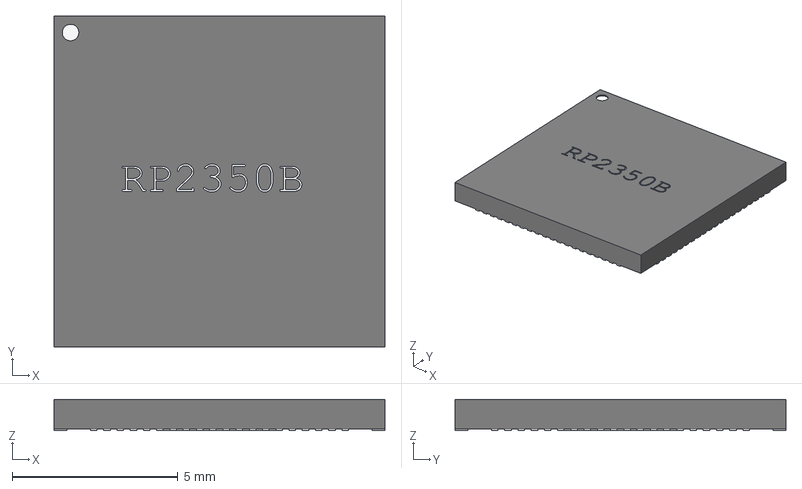
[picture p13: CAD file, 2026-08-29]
Voided-Oblivion/3D-models/RP2350B.step
10.0 x 10.0 x 0.95 mm

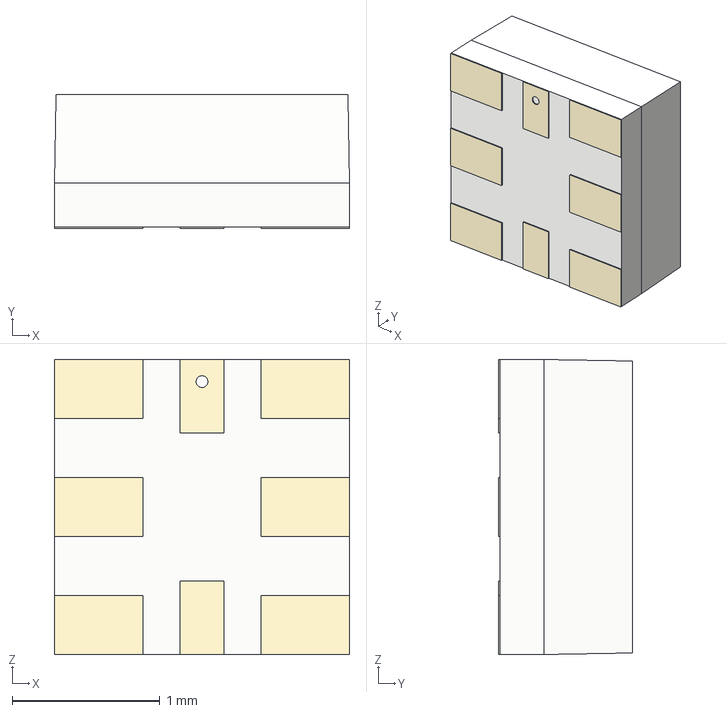
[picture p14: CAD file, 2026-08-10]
Voided-Oblivion/3D-models/sk9822-ec20.step
2.00 x 0.91 x 2.00 mm

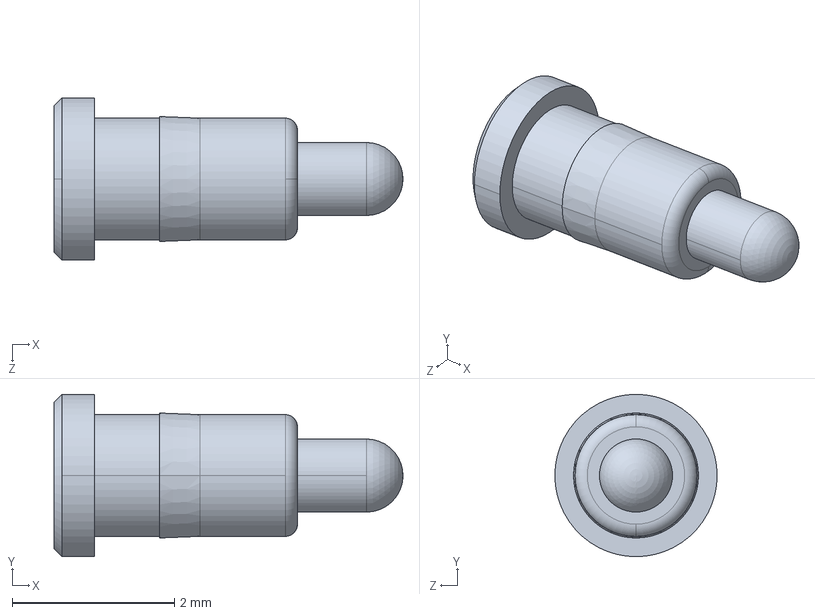
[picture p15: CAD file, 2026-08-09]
Voided-Oblivion/3D-models/pogo-pin.step
4.30 x 2.00 x 2.00 mm

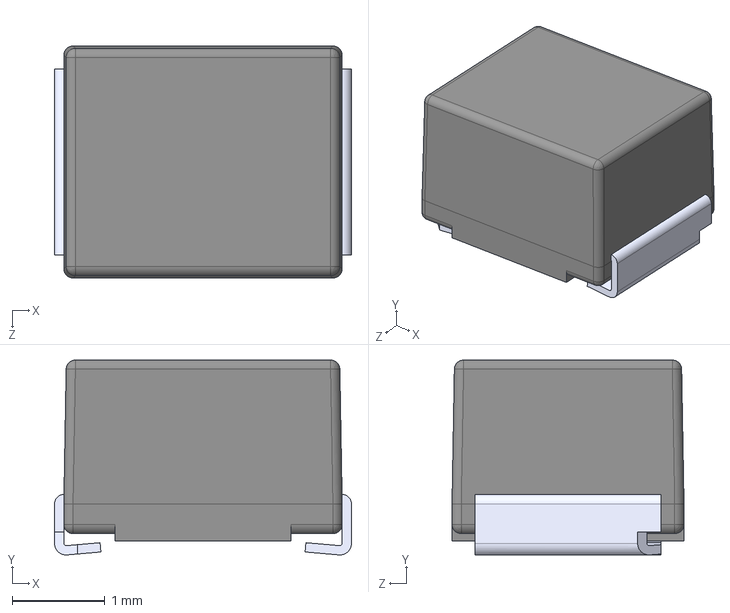
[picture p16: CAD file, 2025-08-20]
kicad_misc_parts/B82422A1332J100.step
3.20 x 2.10 x 2.50 mm

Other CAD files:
Voided-Oblivion/3D-models/PD-2.5-6P-5.5H-SM-RA.FCStd
Voided-Oblivion/3D-models/PG-2.5-6P-5.5H-SM-RA.FCStd

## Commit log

2025-08-24 finished placing components
    [LEDs.kicad_sch, Voided Oblivion.kicad_pcb, Voided Oblivion.kicad_sch]
2025-08-26 schematic done?
    [Voided Oblivion.kicad_pcb, Voided Oblivion.kicad_sch]
2026-06-28 new try
    [B82422A1332J100.step, LEDs.kicad_sch, RP2350A-QFN60.step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]
2026-07-18 power schematic done
    [Voided-Oblivion.kicad_pcb, Voided-Oblivion.kicad_sch, keys.kicad_sch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]
2026-08-09 i think the schematic is acctualy done this time, (besides little tiny things)
    [Voided-Oblivion.kicad_pcb, Voided-Oblivion.kicad_sch, keys.kicad_sch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]
2026-08-10 drc rules and stuff
    [Voided-Oblivion.kicad_pcb, Voided-Oblivion.kicad_sch, keys.kicad_sch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]
2026-08-12 blaaa why does placeing and routing things take so looonnggggggggg >:c
    [Voided-Oblivion.kicad_pcb, Voided-Oblivion.kicad_sch, keys.kicad_sch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]
2026-08-12 the letter "gay"
    [Voided-Oblivion.kicad_pcb]
2026-08-12 i swear bro its for the smaller hitbot
    [Voided-Oblivion.kicad_pcb, Voided-Oblivion.kicad_sch, keys.kicad_sch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]
2026-08-14 still cis tho
    [Voided-Oblivion.kicad_pcb, Voided-Oblivion.kicad_sch, keys.kicad_sch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]
2026-08-16 pcb almooost done
    [Voided-Oblivion.kicad_pcb, Voided-Oblivion.kicad_sch, power.kicad_sch]
2026-08-17 power thinking and stuf
2026-08-18 THE PCB IS FINAWWYY (electricaly) DONE YAAAAAAAAAAAAAA :33333 ^w^ >w<
    [Voided-Oblivion.kicad_pcb, Voided-Oblivion.kicad_sch, power.kicad_sch]
2026-08-18 small changes
    [Voided-Oblivion.kicad_pcb, Voided-Oblivion.kicad_sch, keys.kicad_sch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]
2026-08-20 i think everything but silk is acctualy done this time for reals
    [Voided-Oblivion.kicad_pcb, power.kicad_sch]
2026-08-20 this pcb is being homophobic bro
2026-08-20 BOMB update (ignore the "B" on the end of that first word, it has no significant meaning) and some library linking
    [Voided-Oblivion.kicad_pcb, Voided-Oblivion.kicad_sch, keys.kicad_sch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]
2026-08-20 change thing to vbus instead of pd
    [Voided-Oblivion.kicad_pcb, power.kicad_sch]
2026-08-29 this is gonna be a fun murge :meltingface:
    [BOM-Voided-Oblivion.csv, RP2350B.step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]
2026-09-05 production files i think.com
    [BOM-Voided-Oblivion.csv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]
2026-09-06 boring licence stuff
    [B82422A1332J100.step, BOM-Voided-Oblivion-5x-assembly.csv, BOM-Voided-Oblivion.csv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]
2026-09-07 firmware stuff i thinkg a lil bit
    [keys.kicad_sch]
2026-11-03 inital mechanical design docs (mostly switches rn)
